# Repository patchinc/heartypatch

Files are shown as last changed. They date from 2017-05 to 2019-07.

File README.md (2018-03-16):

ProtoCentral Hearty Patch Single-lead ECG monitor
=======================================================

This repository contains the hardware, firmware and GUI software plans for the HeartyPatch single-lead ECG and R-R interval monitoring device.

## Detailed documentation is available at [heartypatch.protocentral.com](http://heartypatch.protocentral.com/)

For details and updates, check out our Hackaday Page: [https://hackaday.io/project/21046-heartypatch-a-single-lead-ecg-hr-patch-with-esp32](https://hackaday.io/project/21046-heartypatch-a-single-lead-ecg-hr-patch-with-esp32)

You can now buy HeartyPatch at https://www.crowdsupply.com/protocentral/heartypatch

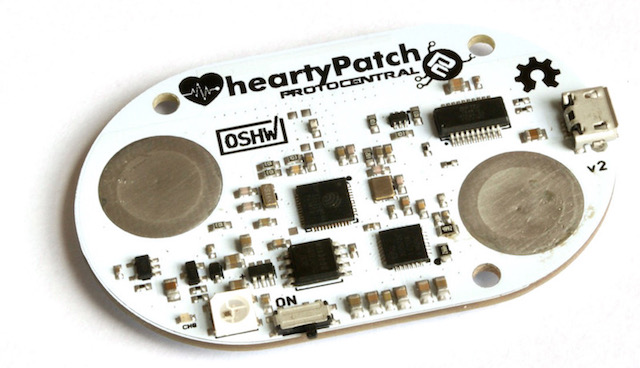
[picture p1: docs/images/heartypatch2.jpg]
HeartyPatch


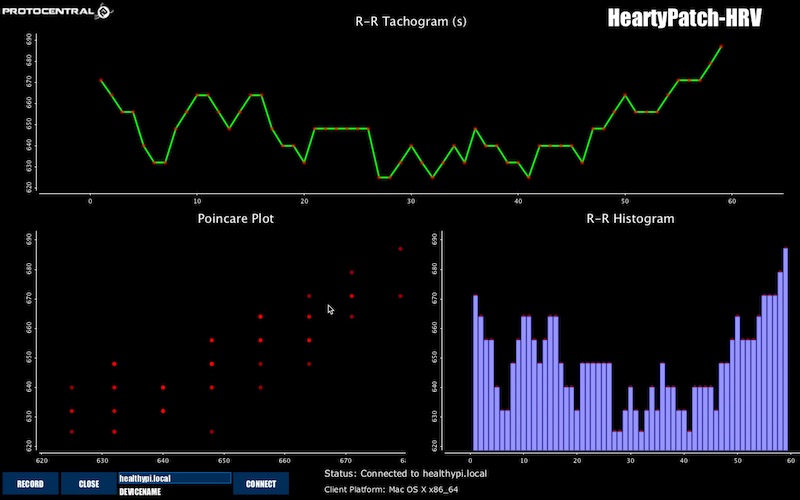
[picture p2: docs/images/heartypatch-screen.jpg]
HeartyPatch Screenshot


License Information
===================

This product is open source! Both, our hardware and software are open source and licensed under the following licenses:

Hardware
---------

**All hardware is released under [Creative Commons Share-alike 4.0 International](http://creativecommons.org/licenses/by-sa/4.0/).**


You are free to:

* Share — copy and redistribute the material in any medium or format
* Adapt — remix, transform, and build upon the material for any purpose, even commercially.
The licensor cannot revoke these freedoms as long as you follow the license terms.

Under the following terms:

* Attribution — You must give appropriate credit, provide a link to the license, and indicate if changes were made. You may do so in any reasonable manner, but not in any way that suggests the licensor endorses you or your use.
* ShareAlike — If you remix, transform, or build upon the material, you must distribute your contributions under the same license as the original.

Software
--------

**All software is released under the MIT License(http://opensource.org/licenses/MIT).**

THE SOFTWARE IS PROVIDED "AS IS", WITHOUT WARRANTY OF ANY KIND, EXPRESS OR IMPLIED, INCLUDING BUT NOT LIMITED TO THE WARRANTIES OF MERCHANTABILITY, FITNESS FOR A PARTICULAR PURPOSE AND NONINFRINGEMENT. IN NO EVENT SHALL THE AUTHORS OR COPYRIGHT HOLDERS BE LIABLE FOR ANY CLAIM, DAMAGES OR OTHER LIABILITY, WHETHER IN AN ACTION OF CONTRACT, TORT OR OTHERWISE, ARISING FROM, OUT OF OR IN CONNECTION WITH THE SOFTWARE OR THE USE OR OTHER DEALINGS IN THE SOFTWARE.

Please check [*LICENSE.md*](LICENSE.md) for detailed license descriptions.

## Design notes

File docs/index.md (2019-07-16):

---
layout: page
homepage: true
---

# Welcome to HeartyPatch
The HeartyPatch

HeartyPatch is a completely open source, single-lead, ECG-HR wearable patch with HRV (Heart Rate Variability) analysis. It is based on the popular ESP32 system-on-a-chip.

If you don't already have one, you can buy one on our [Crowd Supply](https://www.crowdsupply.com/protocentral/heartypatch) campaign page. We have started shipping them out to backers.

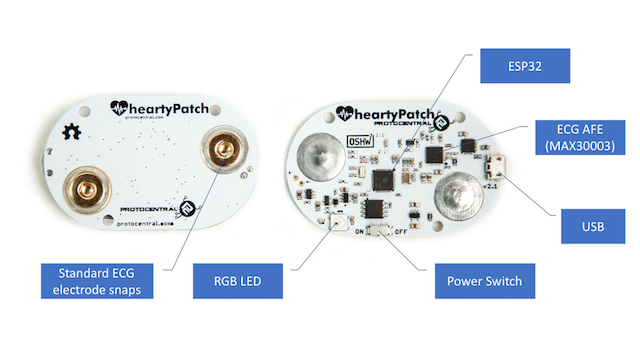
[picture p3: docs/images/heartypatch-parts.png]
HeartyPatch Parts


# Getting Started with HeartyPatch

If you just want to use the HeartyPatch with the pre-loaded firmware, it comes ready to go. You do not have to do any programming to get it working. The pre-loaded firmware send HRV values over BLE.

<iframe src="https://player.vimeo.com/video/249182147" width="640" height="360" frameborder="0" webkitallowfullscreen mozallowfullscreen allowfullscreen></iframe>

## The HeartyPatch App for Android - BETA

An android app for HeartyPatch is now available that receives and displays the real-time heart rate as well as HRV trends and variables. The app scans for any HeartyPatch devices in the vicinity and shows a list of devices accessible through Bluetooth Low Energy (BLE). Please note that you would need an Android device with BLE support to use this app.

You can download and install the app from the [Google Play Store](https://play.google.com/store/apps/details?id=com.protocentral.heartypatch) in the following link:

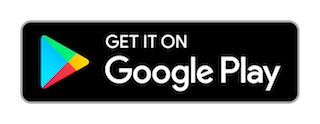
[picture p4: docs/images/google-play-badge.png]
HeartyPatch App for Android (https://play.google.com/store/apps/details?id=com.protocentral.heartypatch)


*Note: The android app for HeartyPatch is still in BETA and there might be some instability as a result.*

*Note: HeartyPatch can also be used with any Android app that supports the heart-rate profile.*

# Modes of operation

HeartyPatch at any time can work in only ONE of the following modes. Wi-Fi and BLE do not work together as of now.

## Bluetooth LE Mode
With the preloaded firmware, the HeartyPatch will do heart-rate and R-R interval measurement and send it over BLE through a standard [Heart-rate BLE service](https://www.bluetooth.com/specifications/gatt/viewer?attributeXmlFile=org.bluetooth.service.heart_rate.xml), as well as a separate custom HRV service that will provide parameters used for HRV analysis such as SD, Mean RR, PNN50 and SDNN.

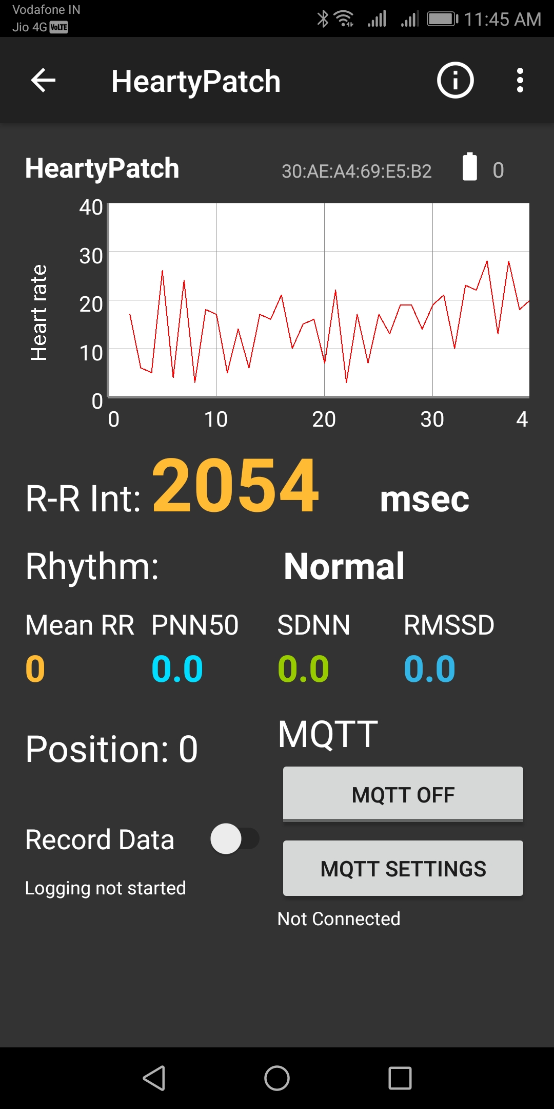
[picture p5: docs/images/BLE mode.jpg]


## Continuous ECG Streaming mode over WiFi/TCP

The HeartyPatch can also do live ECG streaming from the chest. This works similar to a heart-rate monitor. Below is a screen capture of the device working in ECG mode. The data is sent over a TCP socket over WiFi. To get the WiFi mode turned on, you will have to [flash a different firmware onto the device](#continuous-ecg-streaming-mode-over-wifitcp).

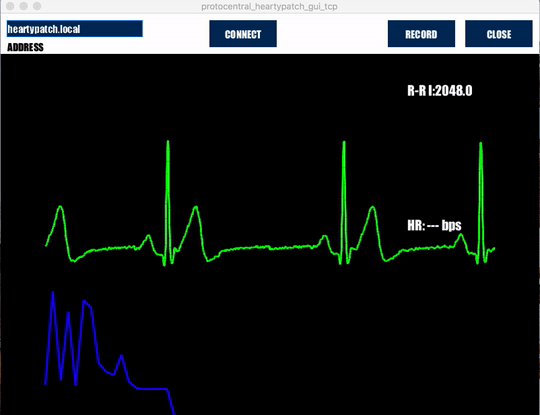
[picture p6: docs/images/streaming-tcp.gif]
HeartyPatch Streaming ECG


# Updating the firmware

It is important to always keep your firmware up-to-date for best results. We keep adding changes, bug fixes and enhancements as and when we do updates. HeartyPatch will continue to be developed and new features added.

Be on the lookout for new firmware releases on our Github releases page at https://github.com/Protocentral/protocentral_heartypatch

Download the latest binary files from the [HeartyPatch Github releases page](https://github.com/Protocentral/protocentral_heartypatch/releases/latest). Binary file names end with xx_bin.zip.

Unzip the files into a folder. Now, plug in your HeartyPatch to your computer through any USB port and follow the following procedures according to your computer's operating system.

## Updating the firmware on MacOS/linux

[esptool](https://github.com/espressif/esptool) is a Python-based utlity program to download binary files onto ESP32 chips. Please follow the following steps to install esptool.

Before starting, you will need to make sure you have Python 2/3 installed on your computer.

Open the termimal on your MacOS/Linux computer and run the command given below to download latest stable esptool.py release.
```c
pip install esptool
```
Now you should be able to run *esptool.py* from the command line. If installation fails, please refer to the [esptool page](https://github.com/espressif/esptool) for possible solutions.

Download the latest binary files from the [HeartyPatch Github releases page](https://github.com/Protocentral/protocentral_heartypatch/releases/latest). Binary file names end with xx_bin.zip.

Unzip the files into a folder.

Now, plug in your HeartyPatch to your computer through any USB port and run the following command from the same folder in which you have unzipped the files.

## Updating BLE firmware in your Heartypatch device 
* Open the unzipped Heartypatch BLE bin files path in your terminal
* Run the command given below

```c
esptool.py --port <your-port-name> write_flash --flash_mode dio --flash_freq 40m --flash_size detect 0x1000 bootloader.bin 0x10000 HeartyPatchBle.bin 0x8000 partitions_singleapp.bin
```

## Updating TCP firmware in your Heartypatch device
* Open the unzipped Heartypatch TCP bin files path in your terminal
* Run the command given below

```c
esptool.py --port <your-port-name> write_flash --flash_mode dio --flash_freq 40m --flash_size detect 0x1000 bootloader.bin 0x10000 heartypatch_tcp.bin 0x8000 partitions_singleapp.bin
```

* We have hardcoded the SSID and Password, hence you have to connect your system with the below provided ssid and password.
* Create a hotspot with ssid and password given below
* SSID - Heartypatch
* Password - 12345678
* Once firmware uploaded connect your system with the created hotspot to see TCP output in processing GUI.

Make sure to replace *<your-port-name>* with the name of the port to which your HeartyPatch. If you get a permission denied error, please run this in "sudo" mode.

If all goes well, you should see the following output on the terminal.

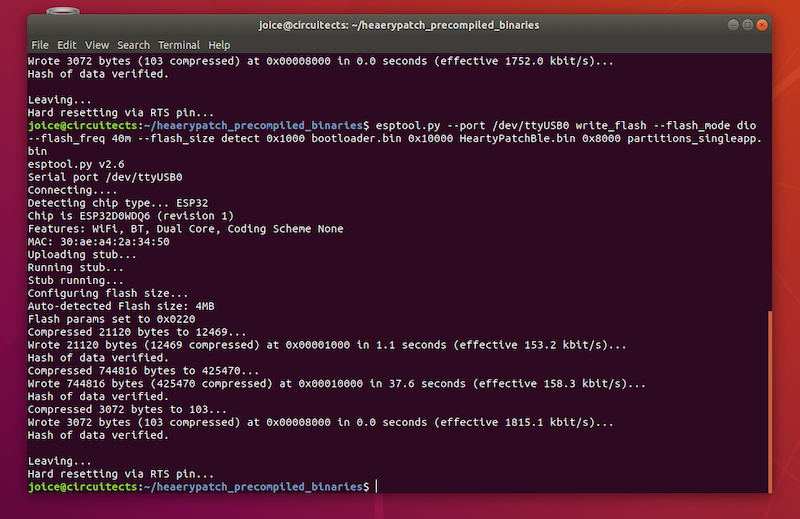
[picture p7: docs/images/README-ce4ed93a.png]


Congratulations ! You have now successfully uploaded the firmware to your HeartyPatch.

## Updating the firmware on Windows

The ESP32 Flash Download Tool is the official Espressif Download tool that runs on Windows platform. The tool can be used to modify and generate init BINs, generate consolidated BIN files or program multiple chips for production runs.

### Installing ESP32 Flash Download Tool

* Download the ESP32 tool from [Espressif's website in tools section](https://www.espressif.com/en/products/hardware/esp32/resources) as shown below

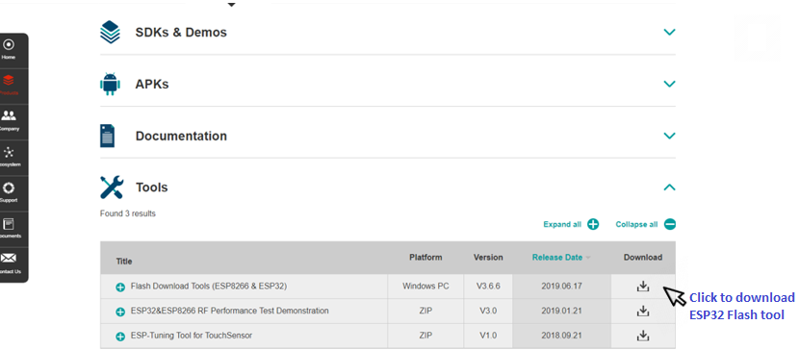
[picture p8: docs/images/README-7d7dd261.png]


* Once downloaded, open the flash_download_tools_v3.6.6.exe application from the downloaded folder as shown below

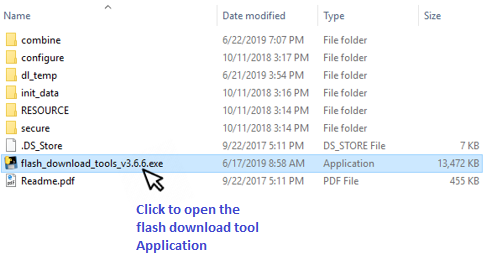
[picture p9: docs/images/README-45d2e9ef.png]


* When the program opens, select *ESP32 Download tool* from the buttons.

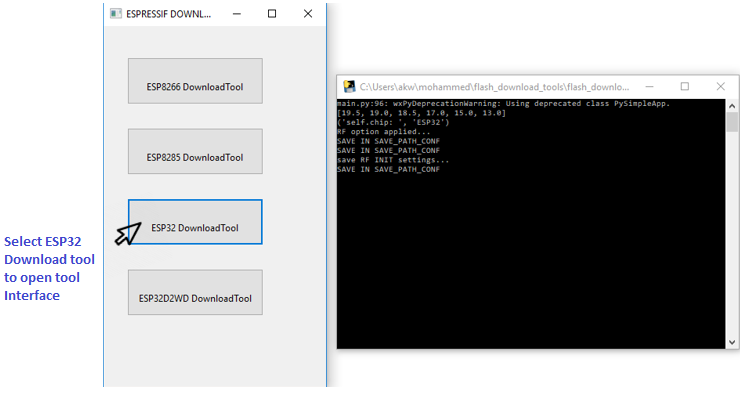
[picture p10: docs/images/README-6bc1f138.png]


* In the resulting window that opens, make sure to select the following options
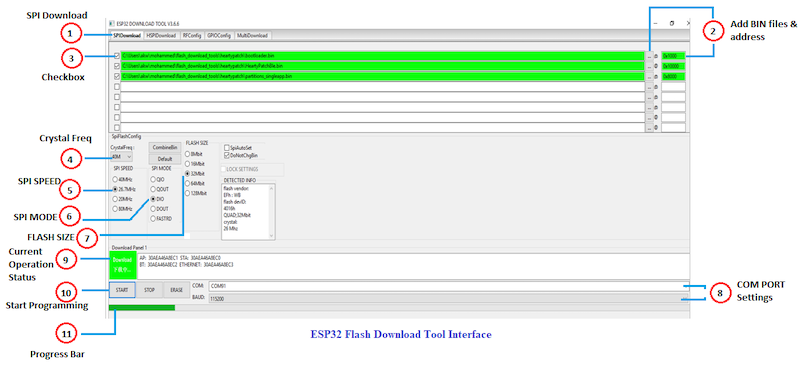
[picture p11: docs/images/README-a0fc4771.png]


1.	SPI download tab. In general, you should use SPI download mode.

2.	Add the bin files downloaded earlier to the ESP32 download tool interface one by one as listed below.

### Heartypatch BLE Command

    * bootloader.bin                   0x1000              
    * HeartyPatchBle.bin               0x10000           
    * partitions_singleapp.bin         0x8000    

### Heartypatch TCP Command

    * bootloader.bin                   0x1000              
    * heartypatch_tcp.bin              0x10000           
    * partitions_singleapp.bin         0x8000 

3.	Click on the check boxes to select the bin files.
4.	Crystal Frequency for heartypatch should be set as 40M.
5.	SPI Flash speed for heartypatch should be set as 26.7MHz.
6.	SPI Mode for heartypatch should be set as DIO mode.
7.	Flash memory size for heartypatch should be set as 32Mbit.
8.	Select the port number of your heartypatch device and set baud rate to 115200.
9.	Current status: Tells about the current operation status. Whether the download tool is idle or running, etc.
10. Click Start button to start programming.
11.	Progress bar indicates firmware uploads program. Once bin files is uploaded the indication status displays finish.
12.	Program displays PHY MAC IDs for Wi-Fi, BLE, ethernet, etc.

Congratulations ! You have now successfully uploaded the firmware to your HeartyPatch.

# Compiling your own firmware (advanced, optional)

The firmware for the HeartyPatch's on-board Espressif ESP32 chip uses the [esp-idf framework](https://github.com/espressif/esp-idf)
 for development. You will need to install and configure the following components to setup a development environment:

* **The Xtensa ESP32 toolchain**
  Please make sure to download the toolchain from the [Espressif Setup Guide for v2.1](http://esp-idf.readthedocs.io/en/v2.1/get-started/index.html#standard-setup-of-toolchain)

  This version of the esp-idf compiles well only with the toolchain version 1.22.0-61-gab8375a-5.2.0.

* **The v2.1 release of esp-idf**
  *The current version of the HeartyPatch code compiles well and performs well only with v2.1 of the ESP-IDF and version 1.22.0-61-gab8375a-5.2.0 of the Xtensa toolchain.*

  [Download the ESP-IDF version 2.1 here](https://github.com/espressif/esp-idf/releases/download/v2.1/esp-idf-v2.1.zip)

  Setup guides for these components are available on the [ESP-IDF documentation site](https://esp-idf.readthedocs.io/en/v2.1/get-started/index.html).

* Clone our [Github repository](https://github.com/Protocentral/protocentral_heartypatch) of code for the ESP32:

  `git clone https://github.com/Protocentral/protocentral_heartypatch.git`

  [or download a zip file of the latest master branch](https://github.com/Protocentral/protocentral_heartypatch/archive/master.zip).

* Download this zip file, rename it to whatever you want to. Change to this directory and then start building.

`Please make sure that correct version of all of the above tools are installed before proceeding.`

The folder "heartypatch-ble" in the "Firmware" contains the code for the preloaded firmware on the HeartyPatch, which calculates R-R interval, heart rate and time domain parameters for HRV analysis and sends them through BLE.

Now that you have the code and ready to build, you will need to configure the build options for heartypatch through menuconfig utility:

* Open the terminal and navigate to the folder which contains the heartypatch code 	
* Start the project configuration utility **menuconfig**     		
  `make menuconfig`

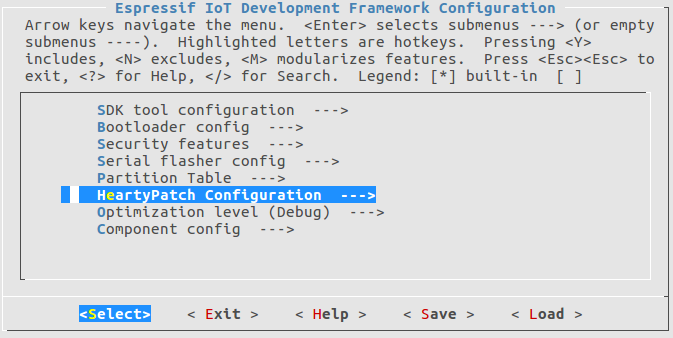
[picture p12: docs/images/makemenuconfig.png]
menuconfig
  

* Configure your serial port under *Serial flasher config -> Default serial port*

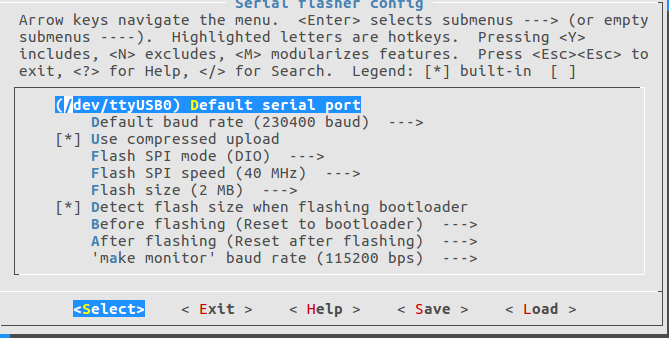
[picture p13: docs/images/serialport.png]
port
  

* Use the *Heartypatch configuration* to enable BLE mode

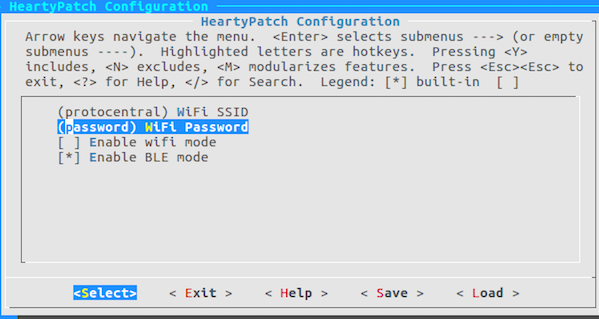
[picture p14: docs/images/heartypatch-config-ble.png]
heartypatch-config
  

BLE mode at this time does not support ECG stream since the MAX30003 sensor is configured for R-R detection only. By enabling the wifi, you may get hr and rr values through TCP in the Heartypatch GUI. For ECG stream you may use the heartypatch-stream-tcp code [protocentral-heartypatch/firmware/heatypatch-stream-tcp]

* Navigate to component config -> esp32-specific ->main XTAL frequency and select 26 Mhz as the board crystal

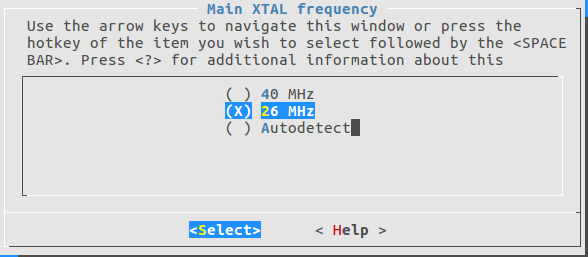
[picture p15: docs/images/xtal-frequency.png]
Setting crystal freqency
  

* Save the configuration by selecting `<save>` and close menuconfig

* Run the makefile (assuming previous steps are done correctly):

  `make` or `make -j5`

* To flash the firmware on to the board, just use:

  `make flash`

  If the flashing is successful, you should see something similar to the below screen:

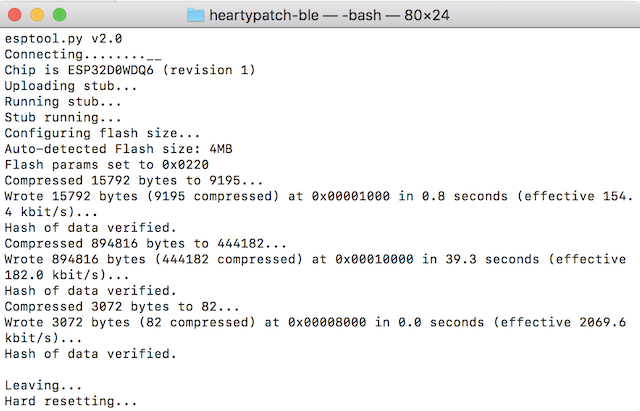
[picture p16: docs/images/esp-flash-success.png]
ESP Success
  

# Continuous ECG mode

The folder `heartypatch-stream-tcp` contains the code for streaming ECG.

Before flashing this code, enable wifi, TCP and mdns through `makemenuconfig` similar to the process described in the previous section.

* Start makemenuconfig and navigate to *Heartypatch configuration*, set your wifi ssid and password, enable mdns and TCP:
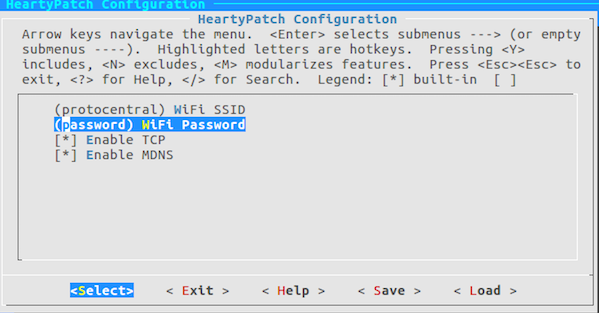
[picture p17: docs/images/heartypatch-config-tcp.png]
Heartypatch config
  

* Configure the serial port under Serial flasher config -> Default serial port
* Navigate to *Component config -> esp32-specific ->main XTAL frequency* and select 26 MHz as the board crystal

Run the makefile (assuming previous steps are done correctly):

`make` or `make -j5`

To flash the firmware on to the board, just use:

`make flash`

If the flashing is successful, you should see something similar to the below screen:

ESP Success

You can open the IDF monitor to see the debug messages by using the command:

`make monitor`

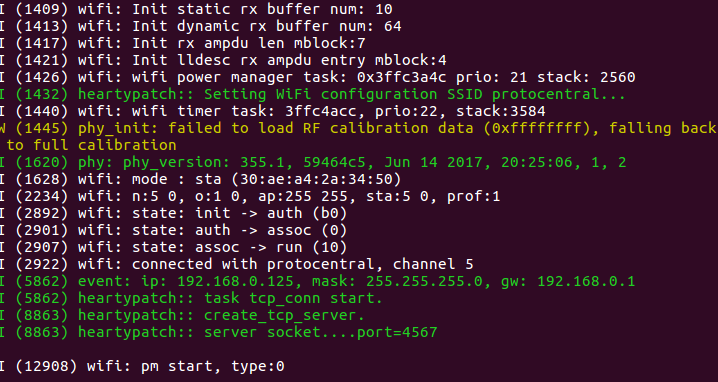
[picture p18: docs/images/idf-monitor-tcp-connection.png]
idf-monitor


Once the heartypatch is connected with the wifi, open the gui from the project folder and you should be able see the ECG stream.  

More information about this process and the ESP32 framework is available in the [ESP32 Get Started Guide](http://esp-idf.readthedocs.io/en/latest/get-started/).

# The TCP Client GUI

The HeartyPatch is now configured as a TCP sever ready for connection from a TCP client. The HeartyPatch sends data out in the following packet format.

| Offset| Byte Value  | Description|
------  | ----------- | -----------
| 0     | 0x0A | Start of frame
| 1     | 0xFA | Start of frame
| 2     | Payload Size LSB |
| 3     | Payload Size MSB |
| 4     | Protocol version | (currently 0x03)
|5-8    | Packet sequence | incremental number
|9-16   | Timestamp | From ESP32 gettimeofday()
|17-20  | R-R Interval |
|18-... | ECG Data samples | Currently 8 samples / packet|
|...    | 0x0B | End of Frame|

You can download the ProtoCentral TCP client GUI for your platform from the following link.

[Download TCP Client GUI](https://github.com/Protocentral/protocentral_heartypatch/releases/latest)

After you unzip and run the executable program on your computer, choose the default address (heartypatch.local) and click connect. You should see a screen like this:

HeartyPatch Streaming ECG

# Frequently Asked Questions

* **Why is the heart-rate not stable? There's always variation.**

  Do not worry, that's what is [Heart-rate variability](https://en.wikipedia.org/wiki/Heart_rate_variability) and HeartyPatch displays real-time beat-to-beat heart rate. Heart-rate is supposed to vary from beat-to-beat.

* **How do I get the full ECG signal from the device?**

  Please read our [Guide to program the device the TCP Streaming mode](#continuous-ecg-mode)

* **I have problems getting the code to compile. What do I do?**

  Most of the problems in compilation arise from having the wrong versions of the ESP-IDF. Please make sure the versions of the esp-idf as well as the Xtensa toochain match the ones given in out [Guide to firmware upgrades](#updating-the-firmware)

* **Help, there is not LED flashing on the device.**

  By default, the LED would not flash. This is done to conserve battery power. This can be enabled in the software though.

* **Why is the ECG  signal too noisy?**

  Noise is very common in ECG systems and they usually use filters to take them out. The HeartyPatch already has hardware as well as software filters to remove noise. However, there are still some conditions which can cause the signal to be noisy:

    * Contact is key. Make sure that the electrode pad is fully flat on the body and it is positioned properly.
    * Make sure that the position of the HeartyPatch is correct (refer to the video). Other positions may not provide a strong signal
    * Do not use the HeartyPatch on the body while it is connected to the USB cable. Always remove the cable before wearing the HeartyPatch.
    * A common source of noise is dry skin. Dry skin does not give good electrical conductivity.
    * Do not re-use ECG electrodes. The quality of contact would reduce with each use.

*We will continue to add to this list based on user input, so please check this list if something goes wrong.*

# License Information

This product is open source! Both, our hardware and software are open source and licensed under the following licenses:

## Hardware

All hardware is released under [Creative Commons Share-alike 4.0 International](http://creativecommons.org/licenses/by-sa/4.0/).



## Software

All software is released under the MIT License(http://opensource.org/licenses/MIT).

Please check [*LICENSE.md*](LICENSE.md) for detailed license descriptions.

THE SOFTWARE IS PROVIDED "AS IS", WITHOUT WARRANTY OF ANY KIND, EXPRESS OR IMPLIED, INCLUDING BUT NOT LIMITED TO THE WARRANTIES OF MERCHANTABILITY, FITNESS FOR A PARTICULAR PURPOSE AND NON-INFRINGEMENT. IN NO EVENT SHALL THE AUTHORS OR COPYRIGHT HOLDERS BE LIABLE FOR ANY CLAIM, DAMAGES OR OTHER LIABILITY, WHETHER IN AN ACTION OF CONTRACT, TORT OR OTHERWISE, ARISING FROM, OUT OF OR IN CONNECTION WITH THE SOFTWARE OR THE USE OR OTHER DEALINGS IN THE SOFTWARE.

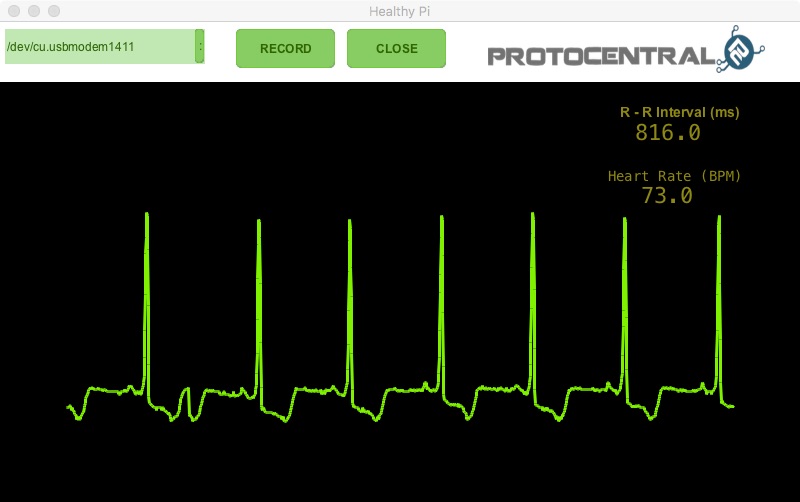
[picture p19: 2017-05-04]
docs/images/max30003_gui_screenshot.jpg

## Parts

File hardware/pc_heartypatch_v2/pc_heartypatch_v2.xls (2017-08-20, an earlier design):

pc_heartypatfch
Qty | Value | Parts | Package
4 | 0.1uF | C20, C36, C37, C41 | 603
4 | 0.1uF | C12, C18,C32, C39 | C0402
1 | 1.0uF | C40 | 603
3 | 1.0uF | C11, C15, C16 | 805
1 | 1.0uF | C19 | C0402
1 | 1000pF | C3 | C0402
1 | 100pF | C35 | 603
1 | 10nF | C31 | 603
2 | 10pF | C27, C28 | 603
2 | 10pF | C9, C10 | C0402
1 | 10uF | C14,C38 | C0603
4 | 10uF | C4, C6, C7, C17 | C0805
2 | 15pF | C42, C43 | 603
1 | 1nF | C2 | C0603
1 | 1uF | C5 | C0402
1 | 1uF | C1 | C0603
2 | 1uF | C8, C13 | C0805
1 | 2.4pF | C33 | 603
1 | 270pF | C30 | 603
1 | 3.0nF | C44 | 603
2 | 4.7u | C21, C22 | C0805
1 | 10K | R20 | R0402
5 | 10k | R1, R2, R3, R21, R29, R30,R33 | 603
1 | 20k | R22 | 603
2 | 1K | R12, R13 | R0402
1 | 1k | R19 | R0402
2 | 49.9K | R4, R5 | 805
1 | 5.6pF | C34 | 603
1 | 330R | R18 | R0402
2 | 27R | R9, R10 | R0402
1 | AP7312 | U$3 | SOT26
1 | BAT20J | D3 | SOD-323
1 | ESP3212 | U10 | QFN48-0.4MM
1 | FTS31XS-U | U4 | SSOP20_L
1 | MAX30003CTI+ | U$1 | QFN-28
1 | MBT3904DW1T1 | Q5 | SC70-6
1 | MCP73831 | U5 | SOT23-5
1 | MICRO-B | JP7 | MICRO-B
1 | PCM12SMTR | S1 | SWITCH-SPST-SMD-A
1 | RED | CHG1 | CHIPLED_0603
1 | W25Q32FVSS | U6 | SOIC-8
1 | WS2812B5050 | LED1 | WS2812B
1 | 2.5A/30V | Q3 | SOT23-3
1 | 2.7nH | L3 | 603
1 | 32.768kHz | Y3 | CRYSTAL-SMD-3.2X1.5MM

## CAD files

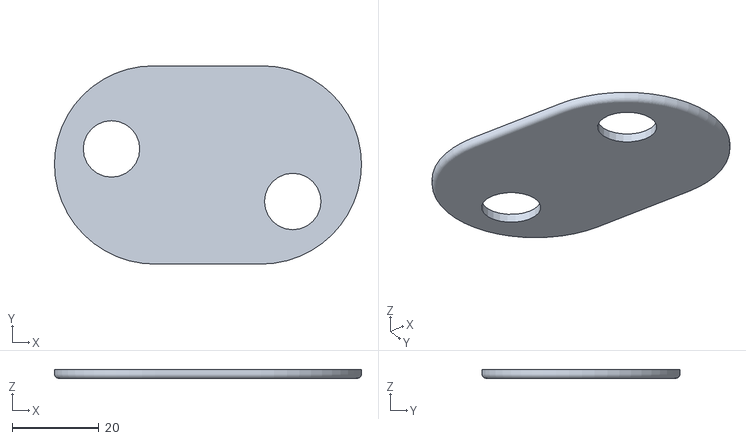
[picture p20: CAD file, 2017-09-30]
hardware/enclosure/heartypatch_case_v2.1/HeartyPatch_ case_v2.1_bottom.stl
70.6 x 45.6 x 2.00

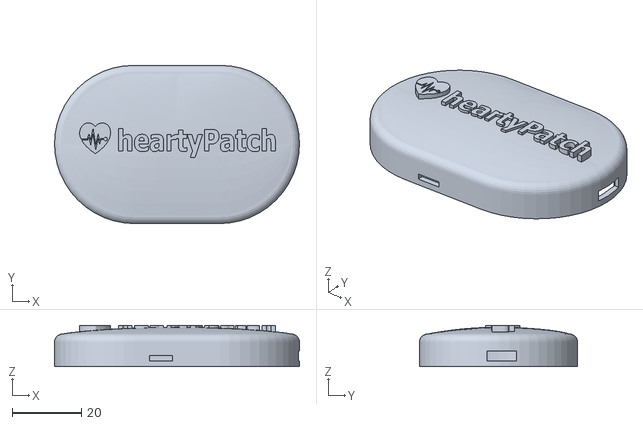
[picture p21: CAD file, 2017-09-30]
hardware/enclosure/heartypatch_case_v2.1/HeartyPatch_ case_v2.1_top.stl
70.6 x 45.6 x 11.9

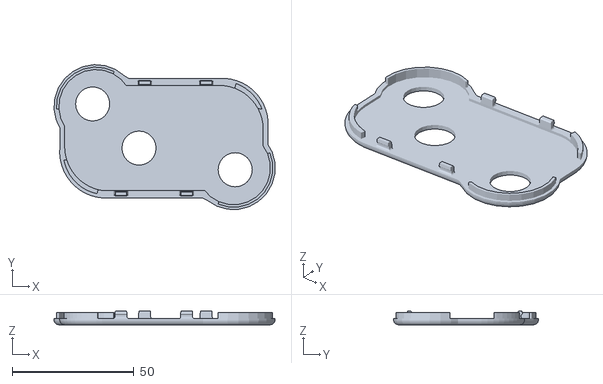
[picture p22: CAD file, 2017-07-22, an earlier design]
hardware/enclosure/heartypatch_case_v1/PCB Bottom Cover with hooks - ShWallHt.stl
90.7 x 59.4 x 5.61

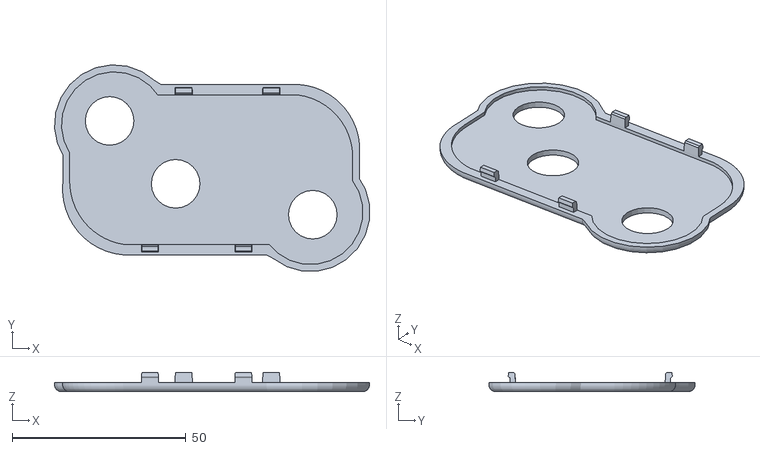
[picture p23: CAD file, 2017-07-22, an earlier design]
hardware/enclosure/heartypatch_case_v1/PCB Bottom Cover with hooks.stl
90.7 x 59.4 x 5.61

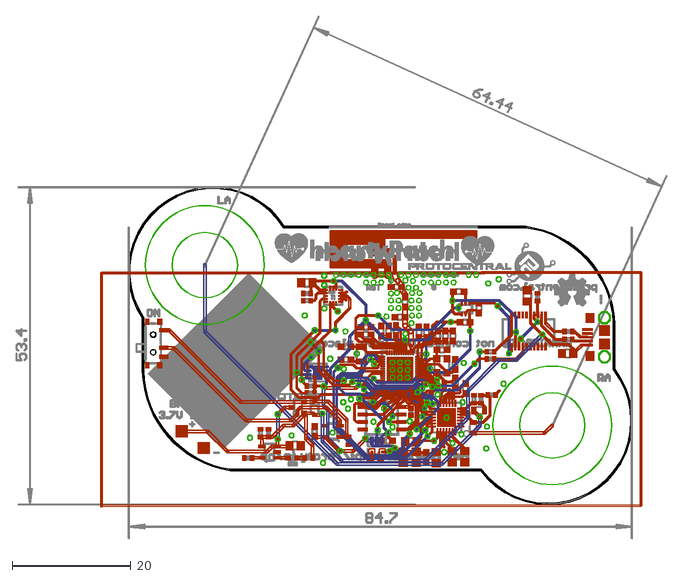
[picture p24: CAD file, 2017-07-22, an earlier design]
hardware/enclosure/heartypatch_case_v1/pc_heartypatch.dxf
109.6 x 87.9

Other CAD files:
hardware/enclosure/heartypatch_case_v1/PCB Bottom Cover with hooks - ShWallHt (1).stl
hardware/enclosure/heartypatch_case_v1/heartyPatch top.skp

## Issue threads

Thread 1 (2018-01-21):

Heart rate returned seems unstable.

ozarchie, 2018-01-21:
I received a HP V2.3 and connected it as per the online video.
I installed the APK on a Nexus7, but the HR value was variable, so I decided to update the firmware.
I installed ESP, and the GITHUB firmware code.
I installed Eclipse as per ESP instructions and compiled and flashed the GITHUB version.
All proceeded correctly,  compiled without errors and flashed without errors.

```
Target 'component-xtensa-debug-module-build' responsible for '/Users/John/esp/heartypatch-ble/build/xtensa-debug-module/libxtensa-debug-module.a'
Flashing binaries to serial port /dev/cu.usbserial-DN02SY6M (app at offset 0x10000)...
python /Users/John/esp/esp-idf/components/esptool_py/esptool/esptool.py --chip esp32 --port "/dev/cu.usbserial-DN02SY6M" --baud 115200 --before "default_reset" --after "hard_reset" write_flash -z --flash_mode "dio" --flash_freq "40m" --flash_size detect 0x1000 /Users/John/esp/heartypatch-ble/build/bootloader/bootloader.bin 0x10000 /Users/John/esp/heartypatch-ble/build/gatt_server_demos.bin 0x8000 /Users/John/esp/heartypatch-ble/build/partitions_singleapp.bin
esptool.py v2.1
Connecting....
Chip is ESP32D0WDQ6 (revision 1)
Uploading stub...
Running stub...
Stub running...
Configuring flash size...
Auto-detected Flash size: 4MB
Flash params set to 0x0220
Compressed 19376 bytes to 11439...

Writing at 0x00001000... (100 %)
Wrote 19376 bytes (11439 compressed) at 0x00001000 in 1.0 seconds (effective 151.4 kbit/s)...
Hash of data verified.
Compressed 730160 bytes to 391849...

Writing at 0x00010000... (4 %)
Writing at 0x00014000... (8 %)
Writing at 0x00018000... (12 %)
Writing at 0x0001c000... (16 %)
Writing at 0x00020000... (20 %)
Writing at 0x00024000... (25 %)
Writing at 0x00028000... (29 %)
Writing at 0x0002c000... (33 %)
Writing at 0x00030000... (37 %)
Writing at 0x00034000... (41 %)
Writing at 0x00038000... (45 %)
Writing at 0x0003c000... (50 %)
Writing at 0x00040000... (54 %)
Writing at 0x00044000... (58 %)
Writing at 0x00048000... (62 %)
Writing at 0x0004c000... (66 %)
Writing at 0x00050000... (70 %)
Writing at 0x00054000... (75 %)
Writing at 0x00058000... (79 %)
Writing at 0x0005c000... (83 %)
Writing at 0x00060000... (87 %)
Writing at 0x00064000... (91 %)
Writing at 0x00068000... (95 %)
Writing at 0x0006c000... (100 %)
Wrote 730160 bytes (391849 compressed) at 0x00010000 in 34.9 seconds (effective 167.4 kbit/s)...
Hash of data verified.
Compressed 3072 bytes to 82...
Writing at 0x00008000... (100 %)
Wrote 3072 bytes (82 compressed) at 0x00008000 in 0.0 seconds (effective 1017.9 kbit/s)...
Hash of data verified.
Leaving...
Hard resetting...
19:43:48 Build Finished (took 44s.339ms)

```
Below is the output of the device connected via USB to the Eclipse monitor.
Either I should be buying a coffin, or something is wrong :)

```
Connected to /dev/cu.usbserial-DN02SY6M at 115200
�ets Jun  8 2016 00:22:57

rst:0x1 (POWERON_RESET),boot:0x13 (SPI_FAST_FLASH_BOOT)
configsip: 0, SPIWP:0xee
clk_drv:0x00,q_drv:0x00,d_drv:0x00,cs0_drv:0x00,hd_drv:0x00,wp_drv:0x00
mode:DIO, clock div:2
load:0x3fff0018,len:4
load:0x3fff001c,len:5544
load:0x40078000,len:0
ho 12 tail 0 room 4
load:0x40078000,len:13724
entry 0x40078fb4
 [0;32mI (30) boot: ESP-IDF v3.1-dev-133-g7d0d2854 2nd stage bootloader [0m
 [0;32mI (30) boot: compile time 19:36:35 [0m
 [0;32mI (39) boot: Enabling RNG early entropy source... [0m
 [0;32mI (39) boot: SPI Speed      : 40MHz [0m
 [0;32mI (39) boot: SPI Mode       : DIO [0m
 [0;32mI (43) boot: SPI Flash Size : 4MB [0m
 [0;32mI (47) boot: Partition Table: [0m
 [0;32mI (51) boot: ## Label            Usage          Type ST Offset   Length [0m
 [0;32mI (58) boot:  0 nvs              WiFi data        01 02 00009000 00006000 [0m
 [0;32mI (66) boot:  1 phy_init         RF data          01 01 0000f000 00001000 [0m
 [0;32mI (73) boot:  2 factory          factory app      00 00 00010000 00100000 [0m
 [0;32mI (81) boot: End of partition table [0m
 [0;32mI (85) esp_image: segment 0: paddr=0x00010020 vaddr=0x3f400020 size=0x2f48c (193676) map [0m
 [0;32mI (161) esp_image: segment 1: paddr=0x0003f4b4 vaddr=0x3ffc0000 size=0x00b5c (  2908) load [0m
 [0;32mI (163) esp_image: segment 2: paddr=0x00040018 vaddr=0x400d0018 size=0x6ccf8 (445688) map [0m
 [0;32mI (322) esp_image: segment 3: paddr=0x000acd18 vaddr=0x3ffc0b5c size=0x02054 (  8276) load [0m
 [0;32mI (326) esp_image: segment 4: paddr=0x000aed74 vaddr=0x40080000 size=0x00400 (  1024) load [0m
 [0;32mI (330) esp_image: segment 5: paddr=0x000af17c vaddr=0x40080400 size=0x1327c ( 78460) load [0m
 [0;32mI (370) esp_image: segment 6: paddr=0x000c2400 vaddr=0x400c0000 size=0x00000 (     0) load [0m
 [0;32mI (382) boot: Loaded app from partition at offset 0x10000 [0m
 [0;32mI (382) boot: Disabling RNG early entropy source... [0m
 [0;32mI (382) cpu_start: Pro cpu up. [0m
 [0;32mI (386) cpu_start: Starting app cpu, entry point is 0x40080f60 [0m
 [0;32mI (0) cpu_start: App cpu up. [0m
 [0;32mI (397) heap_init: Initializing. RAM available for dynamic allocation: [0m
 [0;32mI (403) heap_init: At 3FFAFF10 len 000000F0 (0 KiB): DRAM [0m
 [0;32mI (409) heap_init: At 3FFCAD98 len 00015268 (84 KiB): DRAM [0m
 [0;32mI (415) heap_init: At 3FFE0440 len 00003BC0 (14 KiB): D/IRAM [0m
 [0;32mI (422) heap_init: At 3FFE4350 len 0001BCB0 (111 KiB): D/IRAM [0m
 [0;32mI (428) heap_init: At 4009367C len 0000C984 (50 KiB): IRAM [0m
 [0;32mI (434) cpu_start: Pro cpu start user code [0m
 [0;32mI (5) cpu_start: Starting scheduler on PRO CPU. [0m
 [0;32mI (0) cpu_start: Starting scheduler on APP CPU. [0m
 [0;32mI (2046) gpio: GPIO[27]| InputEn: 1| OutputEn: 0| OpenDrain: 0| Pullup: 0| Pulldown: 1| Intr:1  [0m
 [0;32mI (4046) system_api: Base MAC address is not set, read default base MAC address from BLK0 of EFUSE [0m
 [0;32mI (4226) phy: phy_version: 366.0, ba9923d, Oct 31 2017, 18:06:17, 1, 0 [0m
 [0;32mI (4256) HeartyPatch: REGISTER_APP_EVT, status 0, app_id 0
 [0m
 [0;32mI (4256) HeartyPatch: CREATE_SERVICE_EVT, status 0,  service_handle 40
 [0m
 [0;32mI (4266) HeartyPatch: CREATE_SERVICE_EVT, status 0,  service_handle 44
 [0m
 [0;32mI (4266) HeartyPatch: REGISTER_APP_EVT, status 0, app_id 2
 [0m
 [0;32mI (4276) HeartyPatch: CREATE_SERVICE_EVT, status 0,  service_handle 48
 [0m
 [0;32mI (5026) HeartyPatch: GATT_READ_EVT, conn_id 0, trans_id 4, handle 42
 [0m
 [0;32mI (5126) HeartyPatch: GATT_WRITE_EVT, conn_id 0, trans_id 5, handle 43
 [0m
 [0;32mI (5126) HeartyPatch: GATT_WRITE_EVT, value len 2, value 00000001
 [0m
 [0;32mI (5216) HeartyPatch: GATT_READ_EVT, conn_id 0, trans_id 6, handle 43
 [0m
 [0;32mI (5416) HeartyPatch: GATT_WRITE_EVT, conn_id 0, trans_id 8, handle 47
 [0m
 [0;32mI (5416) HeartyPatch: GATT_WRITE_EVT, value len 2, value 00000001
 [0m
 [0;32mI (5706) HeartyPatch: GATT_WRITE_EVT, conn_id 0, trans_id 11, handle 51
 [0m
 [0;32mI (5706) HeartyPatch: GATT_WRITE_EVT, value len 2, value 00000001
 [0m
hr 3
hr 36
hr 31
hr 31
hr 58
hr 32
hr 61
hr 66
hr 62
hr 60
hr 65
hr 39
hr 67
hr 67
hr 66
hr 61
hr 66
hr 61
hr 60
hr 62
hr 65
hr 62
hr 62
hr 64
hr 64
hr 61
hr 64
hr 66
hr 63
hr 38
hr 70
hr 71
hr 132
hr 55
hr 33
hr 66
hr 61
hr 32
hr 60
hr 60
hr 66
hr 66
hr 61
hr 61
hr 65
hr 132
hr 53
hr 65
hr 66
hr 66
hr 62
hr 139
hr 54
hr 65
hr 65
hr 67
hr 65
hr 65
hr 66
hr 67
hr 125
hr 53
hr 68
hr 69
hr 130
hr 54
hr 69
hr 69
hr 38
hr 67
hr 66
hr 63
hr 64
hr 130
hr 54
hr 63
hr 66
hr 65
hr 64
hr 67
hr 62
hr 38
hr 66
hr 65
hr 63
hr 66
hr 137
hr 53
hr 65
hr 66
hr 67
hr 65
hr 56
hr 112
hr 80
hr 18
hr 120
hr 90
hr 7
hr 65
hr 75
hr 62
hr 87
hr 94
hr 83
hr 92
hr 42
hr 66
hr 44
hr 92
hr 60
hr 13
hr 45
hr 56
hr 96
hr 96
hr 60
hr 97
hr 16
hr 44
hr 96
hr 105
hr 71
hr 120
hr 42
hr 40
hr 89
hr 87
hr 73
hr 69
hr 61
hr 76
hr 89
hr 10
hr 65
hr 66
hr 65
hr 65
hr 67
hr 16
hr 68
hr 70
hr 92
hr 77
hr 73
hr 96
hr 45
hr 29
hr 109
hr 97
hr 60
hr 23
hr 97
hr 36
hr 82
hr 43
hr 97
hr 130
hr 114
hr 153
hr 166
hr 163
hr 103
hr 144
hr 147
hr 232
hr 85
hr 121
hr 38
hr 61
hr 147
hr 106
hr 232
hr 89
hr 38
hr 202
hr 192
hr 202
hr 80
hr 102
hr 102
hr 96
hr 134
hr 66
hr 23
hr 97
hr 156
hr 207
hr 120
hr 182
hr 225
hr 99
hr 225
hr 78
hr 24
hr 142
hr 139
hr 44
hr 84
hr 153
hr 61
hr 61
hr 163
hr 93
hr 225
hr 109
hr 225
hr 31
hr 97
hr 213
hr 24
hr 132
hr 62
hr 114
hr 105
hr 56
hr 65
hr 70
hr 76
hr 27
hr 123
hr 163
hr 41
hr 65
hr 116
hr 98
hr 13
hr 69
hr 72
hr 85
hr 74
hr 23
hr 57
hr 60
hr 77
hr 123
hr 118
hr 125
hr 58
hr 81
hr 116
hr 120
hr 43
hr 13
hr 35
hr 63
hr 102
hr 105
hr 69
hr 105
hr 101
hr 150
hr 57
hr 91
hr 71
hr 51
hr 97
hr 125
hr 66
```
hr 97
hr 139
hr 137
hr 120
hr 130
hr 51
hr 66
hr 219
hr 134
hr 132
hr 137
hr 59
hr 61
hr 232
hr 225
hr 142
hr 232
hr 53
hr 128
hr 174
hr 84
hr 46
hr 11

protocentralashwin, 2018-01-21:
Thank you buying HeartyPatch !

What you're seeing is absolutely correct. The entire purpose of HeartyPatch is to study heart-rate variability. Heart-rate is supposed to change beat-to-beat. Conventional heart-rate monitors only show the average value of the heart rate. Please refer to our earlier post on Crowd Supply about HRV:

https://www.crowdsupply.com/protocentral/heartypatch/updates/heart-rate-vs-heart-rate-variability-hrv

Something is not right only if the heart-rate is very stable!

ozarchie, 2018-01-21:
So I need another device running some other program to make this useful?

protocentralashwin, 2018-01-21:
The whole idea of making HeartyPatch is for studying HRV. However, if you need only average heart-rate, you can average the values over a period of time (usually 1 minute), which is what a conventional heart-rate device does. What is your application? Accordingly you can do the averaging in the software.

ozarchie, 2018-01-21:
OK, thanks.

protocentralashwin, 2018-01-21:
We will add an average function to the app soon. Thanks for letting us know.

ozarchie, 2018-01-21:
I really don't understand or believe  a variation from 27 to 350, but I am
not a health professional.

On 22 Jan. 2018 12:06 am, "Ashwin K Whitchurch" <notifications@github.com>
wrote:

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

protocentralashwin, 2018-01-21:
That is not right of course. It is an artifact, caused by motion of the electrodes or something. We are working on algorithms to remove those artifacts and outliers.

Closed 2018-01-21.

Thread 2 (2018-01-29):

FW Upgrade issue

yursel, 2018-01-29:
I have tried to upgrade the firmware but no success.
Let me tell U the experience:

Linux machine, Ubuntu 16.04

-	xtensa-esp32-elf: I have tried both to build it (successfully) and downloading the pre-built version

-	esp-idf:  here is where the problem probably is.
On your instructions, you mention ( https://github.com/Protocentral/protocentral_heartypatch/blob/master/docs/firmware-upgrades.md ) to use “The v2.1 release of esp-idf”

If I use the checkout of v2.1, I get “make errors” in the app

If I use the checkout of V3.0-rc1, I can build, but I get an error while flashing.
I tried this use because in the dump of the device I see this is the version inside. Please give a look at the screenshot below.

If I use the checkout of V3.0 make app works, but it fails the bootloader make.

Basically, I have not been able to find a working configuration, nor to flash any firmware.

-------- ANSWER from Ashwin (very nice guy!)

I think the problem is with the toolchain. Espressif is not very clear about this. The latest version of the toolchain doesn't work well.

Can you please try out with the toolchain in the following link and let me know?

http://esp-idf.readthedocs.io/en/v2.1/get-started/linux-setup.html

The problem is that v2.1 seems to work only with this toolchain and the v3.0rc1 works with a specific version of the toolchain (not 0.80).

-------- Update on my side

Proposed solution is working, I am able to compile.

Closed 2018-01-29.

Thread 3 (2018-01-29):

Serial port not working in VMware - Solved

yursel, 2018-01-29:
I was trying to use my VM under VMware, by attaching the USB-Serial device to the serial machine.

I was able to read the RX and TX data (like when devices boots up), but not able to enter programming.

I solved the issue by creating a new "Serial port" in the "Virtual Machine Settings".
It works properly, using the standard interrupt mode (not enabling the I/O polling mode).

Hope it can help!

Y

Closed 2018-01-29.

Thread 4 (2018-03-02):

setting it up in ubuntu

sanster9292, 2018-03-02:
Hey guys,
Sorry to put it here, but i just got my heartypatch and I was wondering how i would set it up for use to play around with. I am trying to use the data for some R-R interval realted project I am working on. I was trying to find the link to download the GUI software but I couldn't find any links or tutorials for that.
Any help would be greatly appreciated

joicetm, 2019-02-27:
Hi,

I am closing this issue as it was addressed through mail, you can reopen or create new issue in case of any query

You can check our documentation site for [getting started](http://heartypatch.protocentral.com/)

To record the data you may use the log button in the heartypacth application. which will save the data to a .csv file in downloads section.

[android app](https://play.google.com/store/apps/details?id=com.protocentral.heartypatch&hl=en)

You can also use HeartyPatch GUI to recoed the data while in [TCP mode])https://github.com/Protocentral/protocentral_heartypatch/releases/tag/v1.0)

Closed 2019-02-27.

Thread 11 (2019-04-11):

[FR] Support DIY with ESP32-Dev and AD8232

aenertia, 2019-04-11:
Hi there ; I would like to use Heartypatch code base for my DIY'd ecg running on a clone esp32-dev board and ad8232.

The main challenges are some of the hardcoded assummptions about the max3000 adc chip. It would be great to refactor things a little so that any adc could be dropped in as a pin def/header def and reuse everything else.

aenertia, 2019-04-12:
the AD8232 just returns a reading over Analog ; ideally I just want a data structure where this reading can be returned into and then the rest of the code can remain the same; after undefining the max/spi stuff.

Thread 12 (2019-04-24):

Bluetooth isn´t working - Enable Controller failed

chbardel, 2019-04-24:
I get the following debug messages through serial monitor:
`I (2092) gpio: GPIO[27]| InputEn: 1| OutputEn: 0| OpenDrain: 0| Pullup: 0| Pulldown: 1| Intr:1`
`I (4092) BTDM_INIT: BT controller compile version [484c057]`
`I (4092) system_api: Base MAC address is not set, read default base MAC address from BLK0 of EFUSE`
`E (4092) HeartyPatch: heartypatch_ble_Init enable controller failed`

I wasn´t able to find it via bluetooth on my S9+ with the heartypatch, EliteHRV and various scanner apps. So i decided to reflash the newest firmware. But still I get the above mentioned error messages. Please help!

shashi100, 2019-08-21:
Where you able to resolve this issue? I have the same problem.

chbardel, 2019-08-26:
Na sadly not. Currently it remains useless and lies around in my apartement :/

styck, 2019-10-03:
I was able to use  "make menuconfig" and turn on some debugging then it got around this error.  Seems like a problem in the ESP32, I didn't see anything wrong with the heartypatch code, will investigate more this weekend.  Could be a hard problem if it works turning on debug and doesn't work when it is off.  I'd look for a timing issue then.

styck, 2019-10-04:
I got Bluetooth working, don't think it was code changes but more the changes in the sdkconfig file, I turned off the debugging.  Attached image shows the EliteHRV app and my calibrator showing 100bpm.

My fork has the updated code and configurations: https://github.com/styck/protocentral_heartypatch

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

chbardel, 2020-01-25:
Thanks for the code and your efforts I will try it out as soon as I have time!

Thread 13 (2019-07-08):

Infinite Loop (Reboot) Continuous ECG mode

Badr1600, 2019-07-08:
Error: 18:31:30.257 -> ESP_ERROR_CHECK failed: esp_err_t 0x110c at 0x400df5f5
18:31:30.257 -> file: "C:/msys32/home/100703599/esp/esp-idf/protocentral_heartypatch/firmware/heartypatch-stream-tcp/main/main.c" line 78
18:31:30.257 -> func: kalam_wifi_init
18:31:30.257 -> expression: esp_wifi_init(&cfg)

Complete Trace of Serial Monitor:

18:31:26.696 -> ⸮ets Jun  8 2016 00:22:57
18:31:28.562 ->
18:31:28.562 -> rst:0x1 (POWERON_RESET),boot:0x13 (SPI_FAST_FLASH_BOOT)
18:31:28.562 -> configsip: 0, SPIWP:0x00
18:31:28.562 -> clk_drv:0x00,q_drv:0x00,d_drv:0x00,cs0_drv:0x00,hd_drv:0x00,wp_drv:0x00
18:31:28.562 -> mode:DIO, clock div:3
18:31:28.562 -> load:0x3fff0008,len:8
18:31:28.562 -> load:0x3fff0010,len:4396
18:31:28.562 -> ho 0 tail 12 room 4
18:31:28.562 -> load:0x40078000,len:11080
18:31:28.562 -> ho 0 tail 12 room 4
18:31:28.562 -> load:0x40080000,len:252
18:31:28.562 -> entry 0x40080034
18:31:28.562 ->  [0;32mI (33) boot: ESP-IDF v2.1-dirty 2nd stage bootloader [0m
18:31:28.562 ->  [0;32mI (33) boot: compile time 18:24:24 [0m
18:31:28.562 ->  [0;32mI (60) boot: Enabling RNG early entropy source... [0m
18:31:28.562 ->  [0;32mI (60) boot: SPI Speed      : 26.7MHz [0m
18:31:28.562 ->  [0;32mI (61) boot: SPI Mode       : DIO [0m
18:31:28.562 ->  [0;32mI (73) boot: SPI Flash Size : 4MB [0m
18:31:28.562 ->  [0;32mI (85) boot: Partition Table: [0m
18:31:28.562 ->  [0;32mI (96) boot: ## Label            Usage          Type ST Offset   Length [0m
18:31:28.562 ->  [0;32mI (119) boot:  0 nvs              WiFi data        01 02 00009000 00006000 [0m
18:31:28.562 ->  [0;32mI (142) boot:  1 phy_init         RF data          01 01 0000f000 00001000 [0m
18:31:28.562 ->  [0;32mI (165) boot:  2 factory          factory app      00 00 00010000 00100000 [0m
18:31:28.562 ->  [0;32mI (189) boot: End of partition table [0m
18:31:28.562 ->  [0;32mI (202) boot: Disabling RNG early entropy source... [0m
18:31:28.562 ->  [0;32mI (219) boot: Loading app partition at offset 00010000 [0m
18:31:29.004 ->  [0;32mI (1142) boot: segment 0: paddr=0x00010018 vaddr=0x00000000 size=0x0ffe8 ( 65512)  [0m
18:31:29.004 ->  [0;32mI (1143) boot: segment 1: paddr=0x00020008 vaddr=0x3f400010 size=0x0dd20 ( 56608) map [0m
18:31:29.004 ->  [0;32mI (1159) boot: segment 2: paddr=0x0002dd30 vaddr=0x3ffb0000 size=0x02b1c ( 11036) load [0m
18:31:29.004 ->  [0;32mI (1192) boot: segment 3: paddr=0x00030854 vaddr=0x40080000 size=0x00400 (  1024) load [0m
18:31:29.004 ->  [0;32mI (1213) boot: segment 4: paddr=0x00030c5c vaddr=0x40080400 size=0x13a2c ( 80428) load [0m
18:31:29.004 ->  [0;32mI (1292) boot: segment 5: paddr=0x00044690 vaddr=0x400c0000 size=0x00000 (     0) load [0m
18:31:29.004 ->  [0;32mI (1293) boot: segment 6: paddr=0x00044698 vaddr=0x00000000 size=0x0b970 ( 47472)  [0m
18:31:29.004 ->  [0;32mI (1309) boot: segment 7: paddr=0x00050010 vaddr=0x400d0018 size=0x4bc9c (310428) map [0m
18:31:29.004 ->  [0;32mI (1335) cpu_start: Pro cpu up. [0m
18:31:29.004 ->  [0;32mI (1347) cpu_start: Starting app cpu, entry point is 0x40080ed4 [0m
18:31:29.004 ->  [0;32mI (0) cpu_start: App cpu up. [0m
18:31:29.004 ->  [0;32mI (1380) heap_alloc_caps: Initializing. RAM available for dynamic allocation: [0m
18:31:29.004 ->  [0;32mI (1402) heap_alloc_caps: At 3FFAE2A0 len 00001D60 (7 KiB): DRAM [0m
18:31:29.004 ->  [0;32mI (1423) heap_alloc_caps: At 3FFB8938 len 000276C8 (157 KiB): DRAM [0m
18:31:29.004 ->  [0;32mI (1444) heap_alloc_caps: At 3FFE0440 len 00003BC0 (14 KiB): D/IRAM [0m
18:31:29.004 ->  [0;32mI (1465) heap_alloc_caps: At 3FFE4350 len 0001BCB0 (111 KiB): D/IRAM [0m
18:31:29.004 ->  [0;32mI (1487) heap_alloc_caps: At 40093E2C len 0000C1D4 (48 KiB): IRAM [0m
18:31:29.004 ->  [0;32mI (1508) cpu_start: Pro cpu start user code [0m
18:31:29.004 ->  [0;32mI (1572) cpu_start: Starting scheduler on PRO CPU. [0m
18:31:29.004 ->  [0;32mI (212) cpu_start: Starting scheduler on APP CPU. [0m
18:31:29.614 ->  [0;32mI (837) heartypatch:: max30003_initchip setting SPS to 128 [0m
18:31:29.614 ->  [0;32mI (837) heartypatch:: max30003_initchip DHPF Disabled [0m
18:31:30.086 -> E (1341) wifi: misc_nvs_load 208 ret=4364
18:31:30.257 -> E (1341) wifi: wifi_init 1355 ret=4364
18:31:30.257 -> ESP_ERROR_CHECK failed: esp_err_t 0x110c at 0x400df5f5
18:31:30.257 -> file: "C:/msys32/home/100703599/esp/esp-idf/protocentral_heartypatch/firmware/heartypatch-stream-tcp/main/main.c" line 78
18:31:30.257 -> func: kalam_wifi_init
18:31:30.257 -> expression: esp_wifi_init(&cfg)
18:31:30.257 ->
18:31:30.257 -> Backtrace: 0x40087550:0x3ffb9790 0x400878cd:0x3ffb97b0 0x400df5f5:0x3ffb97d0 0x400df6fd:0x3ffb9890 0x400d0b42:0x3ffb98b0
18:31:30.257 ->
18:31:30.257 -> Rebooting...

Badr1600, 2019-07-08:
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

This message also is printed when using "make" to generate the .bin files for the Continuous ECG mode

styck, 2019-07-09:
I modified the code as shown below.  Keep in mind that I also used a newer tool chain than the one recommended.

//#ifdef CONFIG_MDNS_ENABLE
//      esp_err_t err = mdns_init(TCPIP_ADAPTER_IF_STA, &mdns);
//      ESP_ERROR_CHECK( mdns_set_hostname(mdns, KALAM32_MDNS_NAME) );
//      ESP_ERROR_CHECK( mdns_set_instance(mdns, KALAM32_MDNS_NAME) );
//#endif
#ifdef CONFIG_MDNS_ENABLE
      ESP_ERROR_CHECK( mdns_init() );
      ESP_ERROR_CHECK(mdns_hostname_set(KALAM32_MDNS_NAME));
      ESP_ERROR_CHECK(mdns_instance_name_set(KALAM32_MDNS_NAME));
#endif

Badr1600, 2019-07-10:
@styck still having the same issue. Can you share the .bin files that you built for the continuous ecg firmware to burn it directly to the module. just to verify the idea

styck, 2019-07-10:
This is a zip file with the bin and map file for my build.
[build.zip](https://github.com/Protocentral/protocentral_heartypatch/files/3379613/build.zip)

Badr1600, 2019-07-10:
I think there should be three .bin files heartypatch_tcp.bin, partitions_singleapp.bin and bootloader.bin right ??

styck, 2019-07-10:
Ok, added the bootloader.bin.

[HeartyPatchTCPBinary.zip](https://github.com/Protocentral/protocentral_heartypatch/files/3379706/HeartyPatchTCPBinary.zip)

Badr1600, 2019-07-11:
Great! the firmware is flashed successfully but what is the WiFi ssid and password that was used in the configuration file.

protocentralashwin, 2019-07-11:
Thanks @styck @Badr1600 for solving this issue.  We will upload a new release with the bin files for the continuous ECG mode.

Badr1600, 2019-07-11:
@protocentralashwin Thank you as I think there are some comparability issues with the current esp tool chain and esp-idf while building the firmware. Would be great if you update the instructions on the official website for setting up the firmware to the continuous ECG mode

Badr1600, 2019-07-13:
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

What is the version of tool chain have used ?

styck, 2019-07-13:
Today I just updated to the latest of everything following the instructions for Windows here: https://docs.espressif.com/projects/esp-idf/en/stable/get-started/index.html

There are only a few minor changes that had to be made to the heartypatch code, which I forked and will check in my changes, they just built but I have not tested on the device yet, will continue on this over the weekend.

I would like to add support for Wifi so I don't have to hard code the SSID and password, seems possible looking at: https://github.com/nkolban/esp32-snippets/tree/master/networking/bootwifi

Badr1600, 2019-07-14:
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

Working!!
Fix:
comment this line in file main.c since this attribute is never used and it always raises an error while building the firmware.
//mdns_server_t * mdns = NULL;

joicetm, 2019-07-16:
We are glad that you are able to fix it @Badr1600 @styck . We have updated the release with binaries with mdns and hard coded wifi ssid/password.

Closed 2019-07-15.

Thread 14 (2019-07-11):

Doco: Button and power state not explained

tbaumann, 2019-07-11:
The device has a button.

I believed it's the boot button for the ESP. Or is it power?
I can't actually tell.

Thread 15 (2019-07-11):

Hardware: Beware of original USB cable

tbaumann, 2019-07-11:
I had persistent issues flashing my new HeartyPatch.

Turns out, the USB cable delivered with the device is junk. It works fine with a good one.

To users: Toss it away.

To manufacturer: Leave it out. Everybody has a box full of USB cables. There is no need to bring more junk into the world.

protocentralashwin, 2019-07-11:
@tbaumann Thank you for the suggestion. We haven't seen this issue yet, but will watch out in our future batch of cables

Closed 2019-07-11.

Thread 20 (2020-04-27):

HeartyPatch doesn't show up w/ lsusb (on Linux)

etienneGrossmann, 2020-04-27:
I would like to flash my recently-received heartypatch, v2.3, as explained here https://heartypatch.protocentral.com/.

On my Linux desktop, lsusb does not see it.

How do I determine the port?

etienneGrossmann, 2020-04-29:
It now shows up. Was it because it was not charged?

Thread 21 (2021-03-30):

Basic diag for device

tralfamadude, 2021-03-30:
I want to use my v2.3 heartypatch again after a few years of sitting idle. Previously I got it to work with "Elite HRV" app on my iphone. Now the device is not detected by that app.

The charge LED goes on when it has usb power, but that red LED does not stay on for more than 30sec. Does that mean it is charged or something else?

I don't see it show up as a USB device on my macbook. Does that mean the device is broken?

The RGB LED never lights up.

dice2k, 2021-09-26:
Bottom line. Your electronics are probably still good... just a bad battery.

I just pulled my v2.3 out after a few years.

The Li-Po battery looked like a fat pillow. This means it has stopped working and will need a new battery. These batteries are easily replaceable but ideally will be removed and replaced using a soldering iron.

I am replacing mine with an 18650 LiFePo battery holder so I can simply replace the cells when needed.

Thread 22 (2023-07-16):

Migration to ESPhome?

SamSmith17, 2023-07-16:
Hi there, I have two heartypatches, and this repo seems defunct. That's just an observation, not a judgement, I know how it goes and appreciate all the work that went into this project.

I'm wondering if anyone knows how to port this project over to ESPhome for Home Assistant? It seems like this board is an ESP32 connected to a MAX30003 chip, basically like a stock ESP connected the to the Protocentral MAX30003 breakout board, just integrated into one board. ESPhome doesn't have a native component for the MAX30003 (yet) but I know that ESPhome configs can include C++ arduino code and libraries using the "Custom Component" template, and so I'm wondering if it might be possible to just use the ESP to push the R-R output values coming from the MAX30003 chip over wifi to HA so that they can be processed/filtered/interpreted elsewhere. In that case, I think the C++ code would only need to include the code and libraries for MAX chip and whatever signal processing may be necessary, and would not need to include the BLE or TCP functionality, which seems to be the majority of the code in this repo. I'm want to try it because these heartypatches I have aren't particularly useful to me running the stock firmware, but migrating to ESPhome is a bit above my paygrade, and so if anyone has input on how this might be done, or if there is a reason it absolutely cannot be done, I'd love to know. Is there a GPIO pin on the ESP I could set to just read the R-R output of the MAX30003?

Thanks for this project, these are neat little boards!

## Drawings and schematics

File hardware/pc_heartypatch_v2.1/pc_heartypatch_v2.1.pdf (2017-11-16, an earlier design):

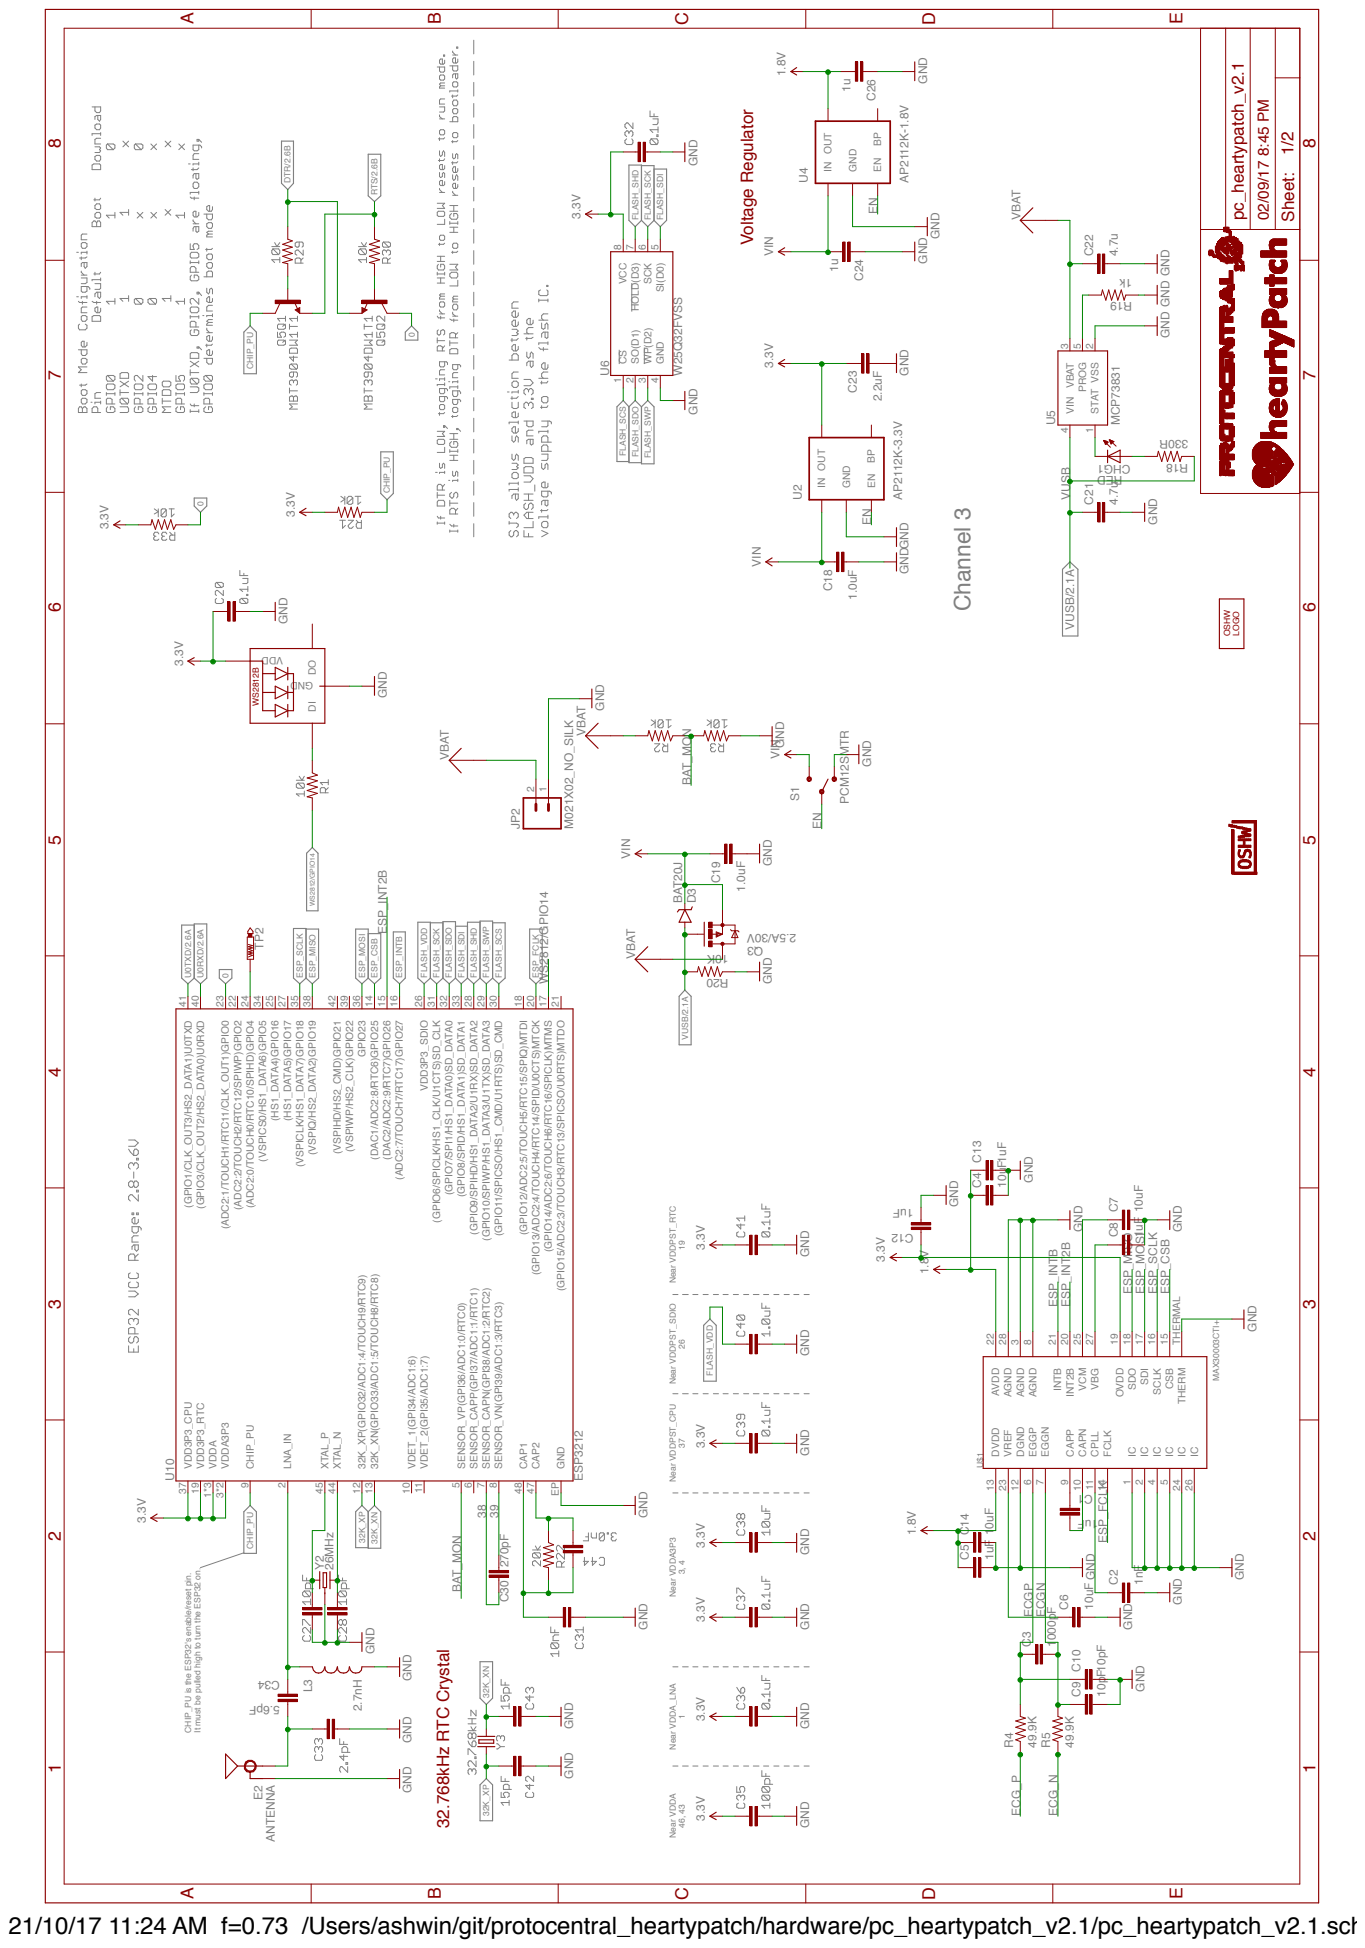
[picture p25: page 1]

GND 4 SCK 6 SI(D0) 5 SO(D1) 2 VCC 8

CSB 15 SCLK 16 SDI 17 SDO 18 OVDD 19

CHIP_PU is the ESP32's enable/reset pin.

It must be pulled high to turn the ESP32 on.

21/10/17 11:24 AM f=0.73 /Users/ashwin/git/protocentral_heartypatch/hardware/pc_heartypatch_v2.1/pc_heartypatch_v2.1.sch (Sheet: 1/2) Near VDDA 46, 43 Near VDDA_LNA

21/10/17 11:24 AM f=1.08 /Users/ashwin/git/protocentral_heartypatch/hardware/pc_heartypatch_v2.1/pc_heartypatch_v2.1.sch (Sheet: 2/2) GND MICRO⁻B | CP²¹⁰⁴ GND GND | GND

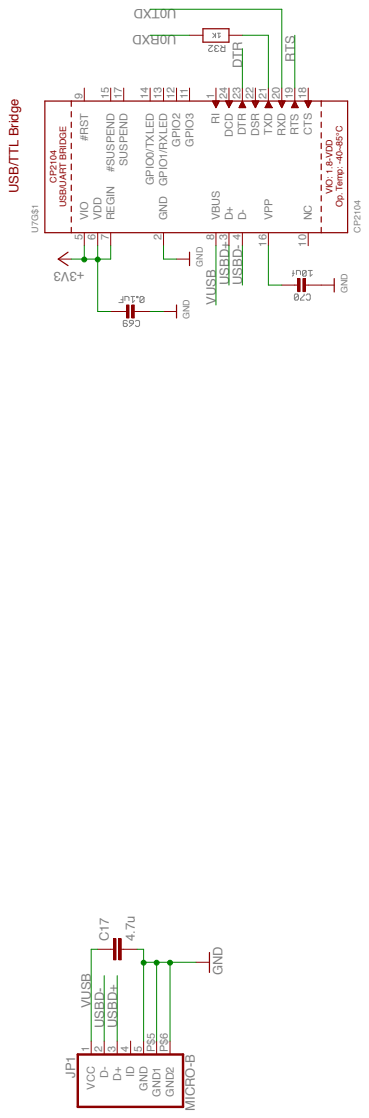
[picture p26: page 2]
VCC 1; GND 5; GND1 P$5; GND2 P$6; GND 2; VIO 5; VDD 6; REGIN 7; VBUS 8; #RST 9; GPIO3 11 GPIO2 12; DCD 24; DTR 23; DSR 22; TXD 21; RXD 20; RTS 19; CTS 18; SUSPEND 17; VPP 16; #SUSPEND 15; GPIO0/TXLED 14; GPIO1/RXLED 13; VUSB; USBD+; USBD-; RTS DTR; pc_heartypatch_v2.1; 2/2 Sheet:; VIO: 1.8-VDD; Op. Temp: -40~85°C

USB/TTL Bridge

USB/UART BRIDGE

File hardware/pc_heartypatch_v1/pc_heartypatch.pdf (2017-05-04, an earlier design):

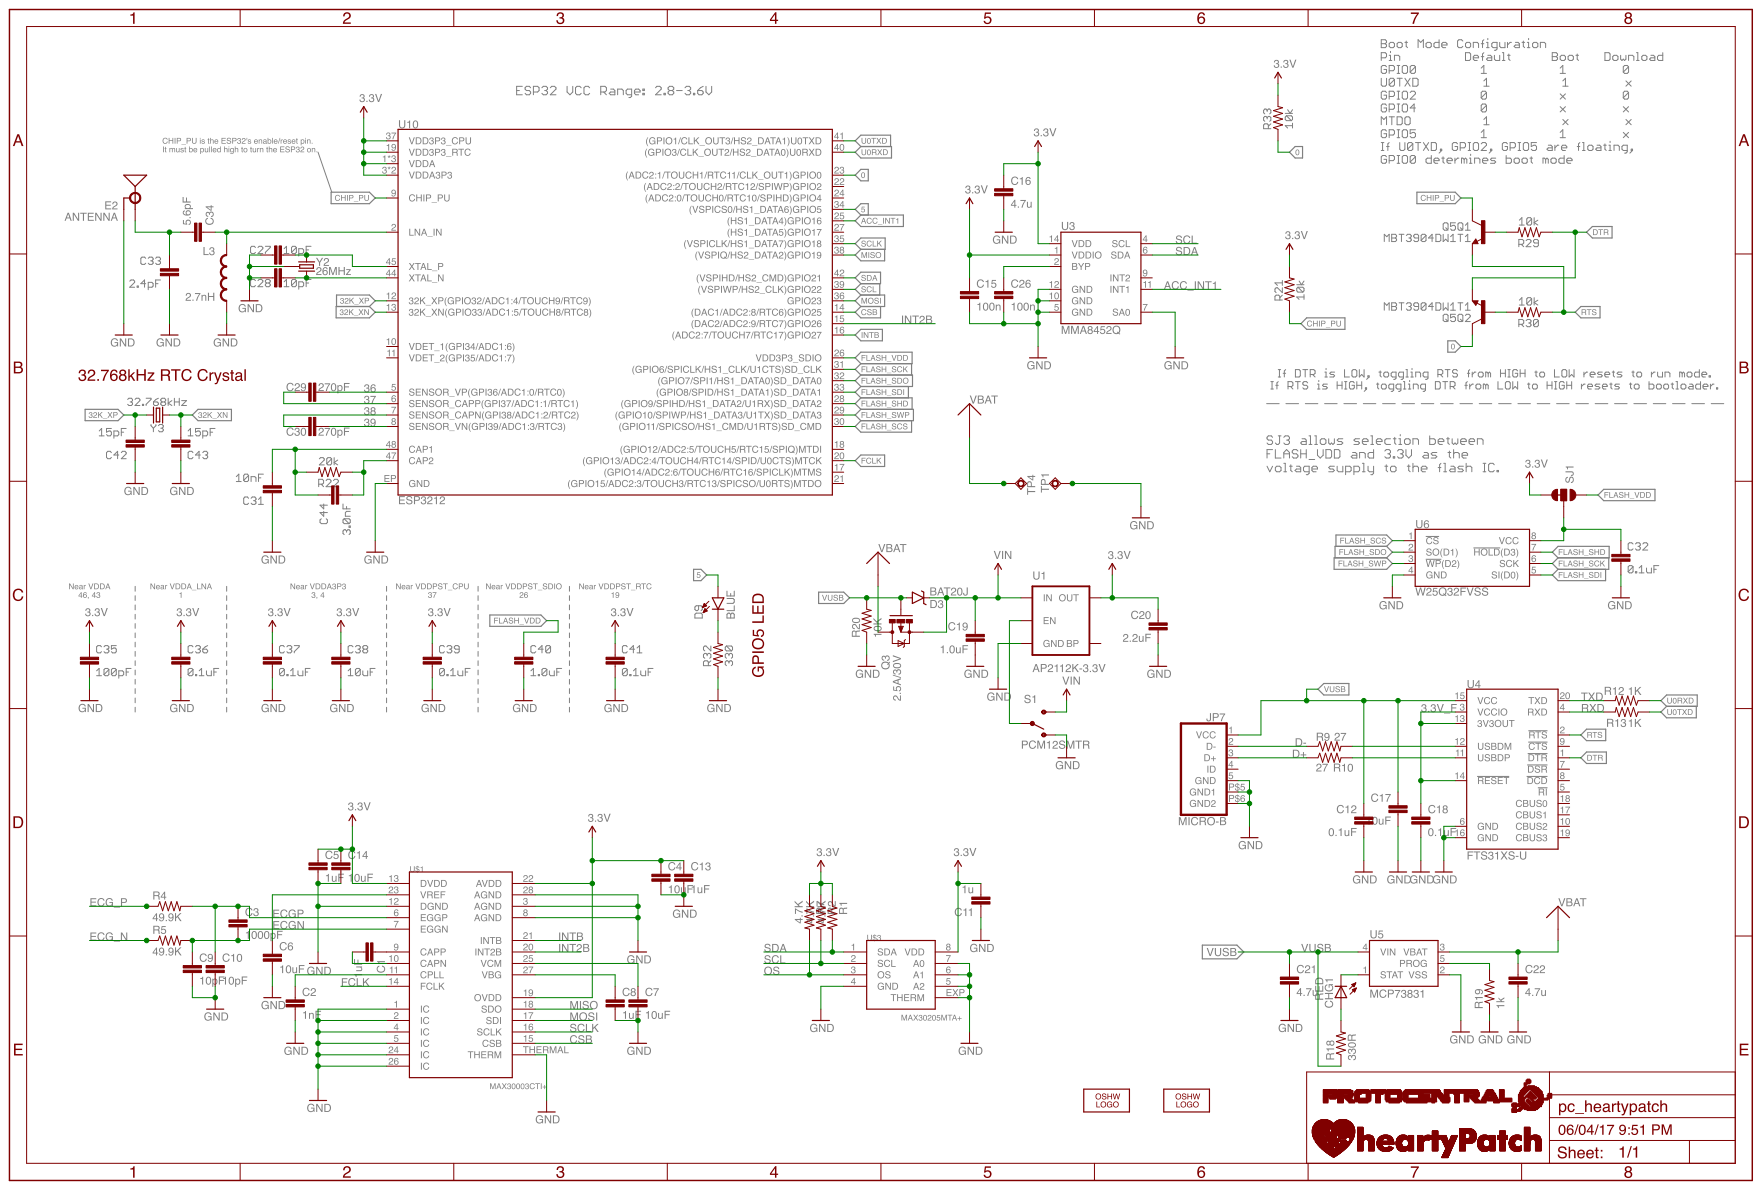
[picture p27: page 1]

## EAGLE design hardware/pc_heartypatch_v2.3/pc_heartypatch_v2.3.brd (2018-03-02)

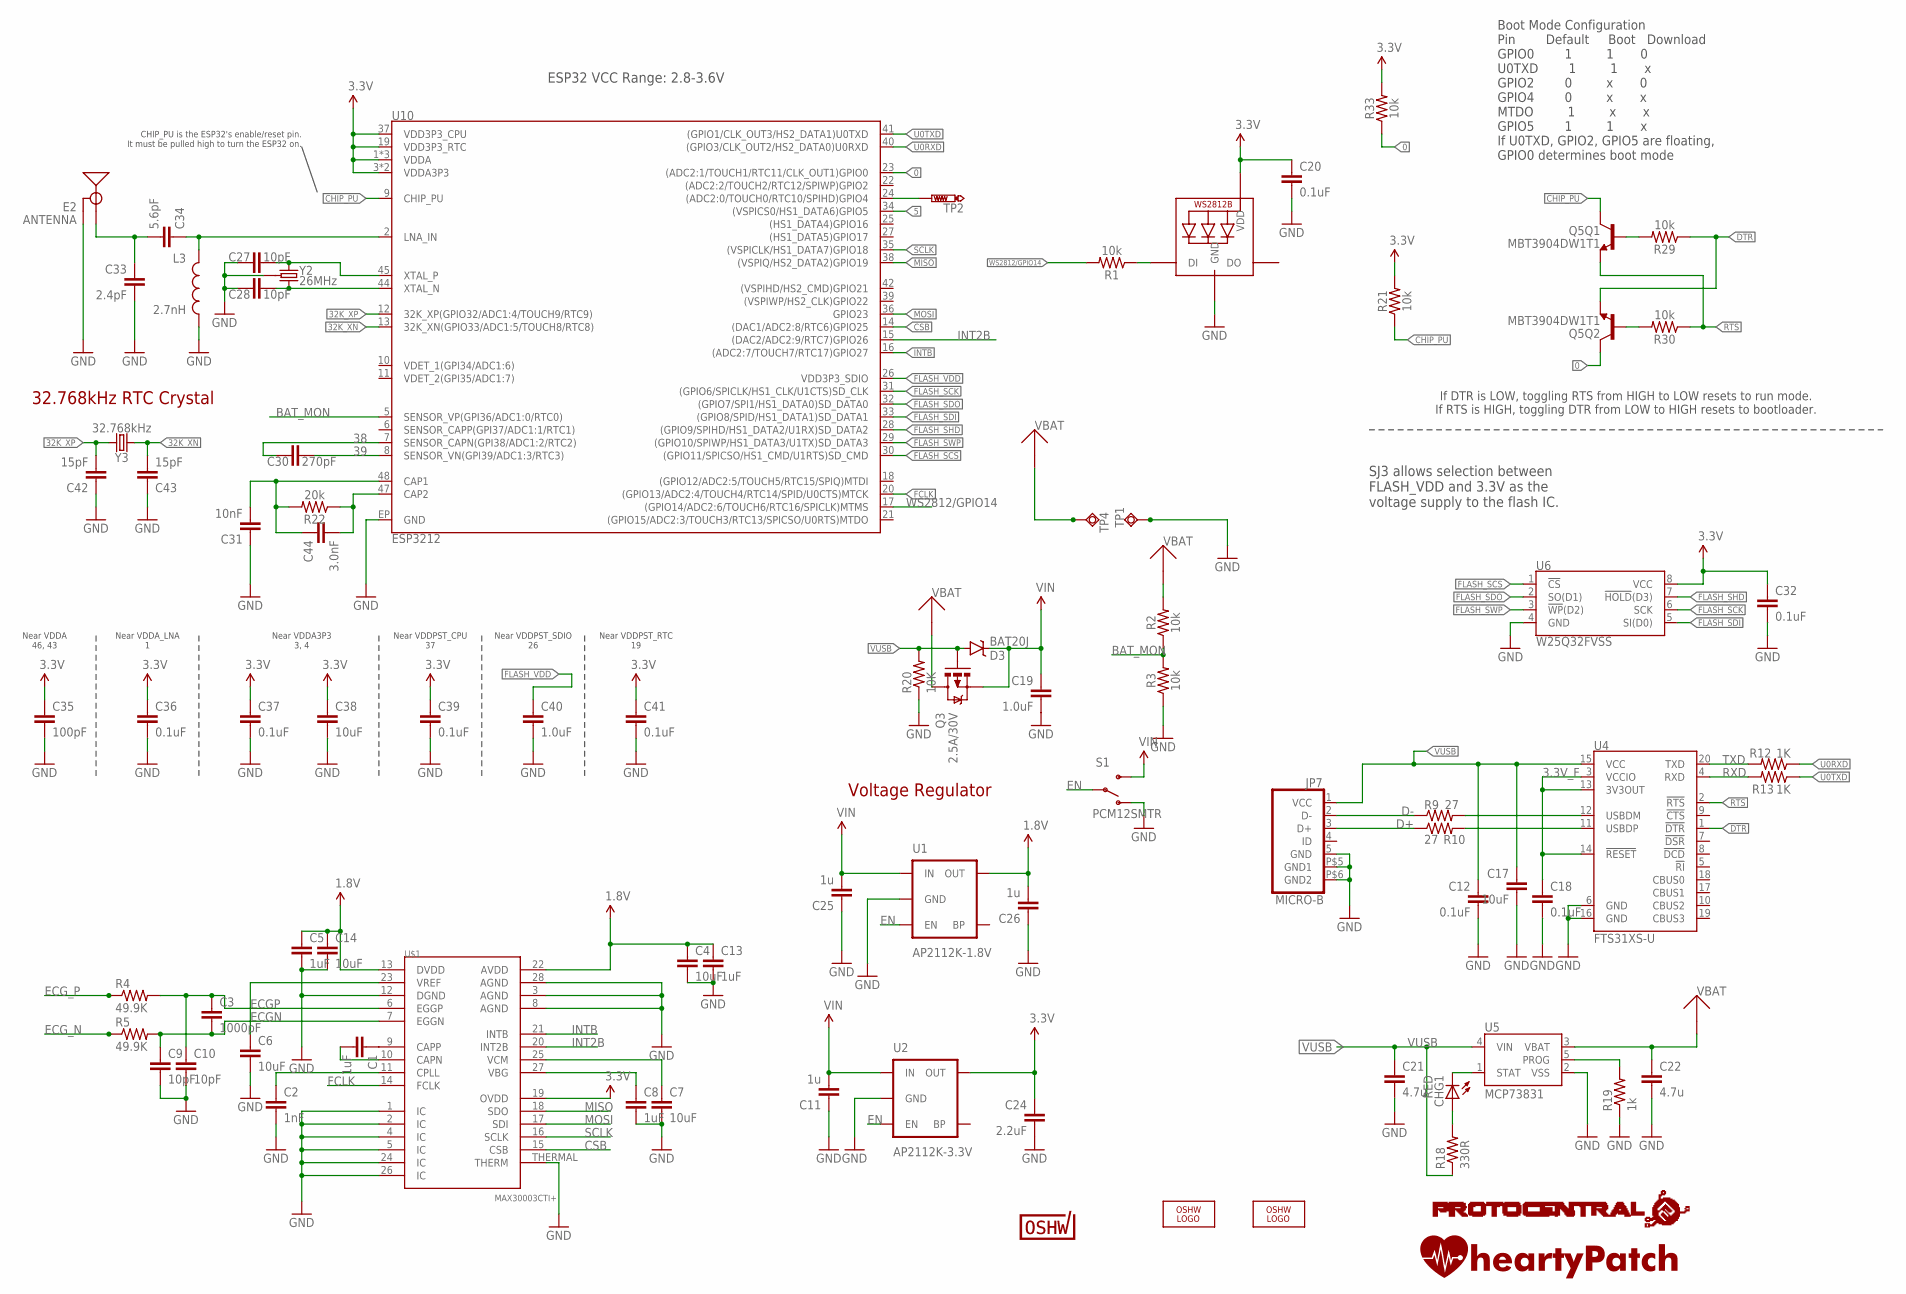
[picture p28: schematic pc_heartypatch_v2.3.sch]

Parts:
C1: 1uF; C0603
C2: 1nF; C0603
C3: 1000pF; C0402
C4, C6, C7, C17: 10uF; C0805
C5: 1uF; C0402
C8, C13: 1uF; C0805
C9, C10: 10pF; C0402
C11, C25, C26: 1u; C0402
C12, C18: 0.1uF; C0402
C14: 10uF; C0603
C19: 1.0uF; C0402
C20, C36, C37, C41: 0.1uF; 0603
C21, C22: 4.7u; C0805
C24: 2.2uF; C0402
C27, C28: 10pF; 0603
C30: 270pF; 0603
C31: 10nF; 0603
C32, C39: 0.1uF; 0402
C33: 2.4pF; 0603
C34: 5.6pF; 0603
C35: 100pF; 0603
C38: 10uF; 0603
C40: 1.0uF; 0603
C42, C43: 15pF; 0603
C44: 3.0nF; 0603
CHG1: RED; CHIPLED_0603
D3: BAT20J; SOD-323
E2: ANTENNA; TRACE_ANTENNA_2.4GHZ_25.7MM_TUNED
JP7: MICRO-B
L3: 2.7nH; 0603
LED1: WS2812B5050; WS2812B
LOGO1, LOGO2: OSHW_LOGO_FILLX0200-NT; OSHW_FILLX200_NOTEXT
Q3: 2.5A/30V; SOT23-3
Q5: MBT3904DW1T1; SC70-6
R1, R2, R3, R21, R29, R30, R33: 10k; 0603
R4, R5: 49.9K; 0805
R9, R10: 27; R0402
R12, R13: 1K; R0402
R18: 330R; R0402
R19: 1k; R0402
R20: 10K; R0402
R22: 20k; 0603
S1: PCM12SMTR; SWITCH-SPST-SMD-A
TP1, TP4: TPSQTP20SQ; TP20SQ
TP2: PTR1TP10SQ; TP10SQ
U1: AP2112K-1.8V; SOT23-5
U2: AP2112K-3.3V; SOT23-5
U4: FTS31XS-U; SSOP20_L
U5: MCP73831; SOT23-5
U6: W25Q32FVSS; SOIC-8
U10: ESP3212; QFN48-0.4MM
U$1: MAX30003CTI+; QFN-28
U$8: HEARTYPATCHHEART; HEARTYPATCH
U$9: PROTY_LOGO_WITH_TEXT; PROTY_WITH_TEXT
U$10: CERT-SMALL; CERT-SMALL-SILK
Y2: 26MHz; CRYSTAL-SMD-3.2X2.5
Y3: 32.768kHz; CRYSTAL-SMD-3.2X1.5MM

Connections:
0: Q5.6 (C), R33.1, U10.23 ((ADC2:1/TOUCH1/RTC11/CLK_OUT1)GPIO0)
1.8V: C4.1, C5.1, C13.1, C14.1, C26.2, U1.5 (OUT), U$1.13 (DVDD), U$1.22 (AVDD)
3.3V: C20.1, C24.1, C32.1, C35.1, C36.1, C37.1, C38.1, C39.1, C41.1, LED1.1-VDD (VDD), R21.2, R33.2, U2.5 (OUT), U6.8 (VCC), U10.1 (VDDA), U10.3 (VDDA3P3), U10.4 (VDDA3P3), U10.19 (VDD3P3_RTC), U10.37 (VDD3P3_CPU), U10.43 (VDDA), U10.46 (VDDA), U$1.19 (OVDD)
3.3V_F: C18.1, U4.3 (VCCIO), U4.13 (3V3OUT), U4.14 (!RESET)
5: U10.34 ((VSPICS0/HS1_DATA6)GPIO5)
32K_XN: C43.2, U10.13 (32K_XN(GPIO33/ADC1:5/TOUCH8/RTC8)), Y3.P$2 (2)
32K_XP: C42.2, U10.12 (32K_XP(GPIO32/ADC1:4/TOUCH9/RTC9)), Y3.P$1 (1)
38: C30.1, U10.7 (SENSOR_CAPN(GPI38/ADC1:2/RTC2))
39: C30.2, U10.8 (SENSOR_VN(GPI39/ADC1:3/RTC3))
BAT_MON: R2.1, R3.2, U10.5 (SENSOR_VP(GPI36/ADC1:0/RTC0))
CAP_10N: C31.2, C44.1, R22.2, U10.48 (CAP1)
CHIP_PU: Q5.3 (C), R21.1, U10.9 (CHIP_PU)
CSB: U10.14 ((DAC1/ADC2:8/RTC6)GPIO25), U$1.15 (CSB)
D+: JP7.3 (D+), R10.1
D-: JP7.2 (D-), R9.1
DTR: Q5.1 (E), R29.1, U4.1 (!DTR)
ECGN: C3.2, C9.1, R5.2, U$1.7 (EGGN)
ECGP: C3.1, C10.1, R4.2, U$1.6 (EGGP)
ECG_N: R5.1
ECG_P: R4.1
EN: S1.2, U1.3 (EN), U2.3 (EN)
FCLK: U10.20 ((GPIO13/ADC2:4/TOUCH4/RTC14/SPID/U0CTS)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), U$1.14 (FCLK)
FLASH_SCK: U6.6 (SCK), U10.31 ((GPIO6/SPICLK/HS1_CLK/U1CTS)SD_CLK)
FLASH_SCS: U6.1 (!CS!), U10.30 ((GPIO11/SPICSO/HS1_CMD/U1RTS)SD_CMD)
FLASH_SDI: U6.5 (SI(D0)), U10.33 ((GPIO8/SPID/HS1_DATA1)SD_DATA1)
FLASH_SDO: U6.2 (SO(D1)), U10.32 ((GPIO7/SPI1/HS1_DATA0)SD_DATA0)
FLASH_SHD: U6.7 (!HOLD!(D3)), U10.28 ((GPIO9/SPIHD/HS1_DATA2/U1RX)SD_DATA2)
FLASH_SWP: U6.3 (!WP!(D2)), U10.29 ((GPIO10/SPIWP/HS1_DATA3/U1TX)SD_DATA3)
FLASH_VDD: C40.1, U10.26 (VDD3P3_SDIO)
GND: C2.2, C4.2, C5.2, C6.2, C7.2, C8.2, C9.2, C10.2, C11.1, C12.2, C13.2, C14.2, C17.2, C18.2, C19.2, C20.2, C21.2, C22.2, C24.2, C25.1, C26.1, C27.1, C28.1, C31.1, C32.2, C33.2, C35.2, C36.2, C37.2, C38.2, C39.2, C40.2, C41.2, C42.1, C43.1, E2.GND, E2.GND2 (GND), JP7.5 (GND), JP7.P$5 (GND1), JP7.P$6 (GND2), L3.2, LED1.3-GND (GND), R3.1, R19.1, R20.1, S1.1 (O), TP1.TP, U1.2 (GND), U2.2 (GND), U4.6 (GND), U4.16 (GND), U5.2 (VSS), U6.4 (GND), U10.EP (GND), U$1.1 (IC), U$1.2 (IC), U$1.3 (AGND), U$1.4 (IC), U$1.5 (IC), U$1.8 (AGND), U$1.12 (DGND), U$1.24 (IC), U$1.26 (IC), U$1.28 (AGND), U$1.THERMAL (THERM), Y2.2 (GND), Y2.4 (GND)
INT2B: U10.15 ((DAC2/ADC2:9/RTC7)GPIO26), U$1.20 (INT2B)
INTB: U10.16 ((ADC2:7/TOUCH7/RTC17)GPIO27), U$1.21 (INTB)
LNA_IN: C34.1, L3.1, U10.2 (LNA_IN)
MISO: U10.38 ((VSPIQ/HS2_DATA2)GPIO19), U$1.18 (SDO)
MOSI: U10.36 (GPIO23), U$1.17 (SDI)
unnamed: LED1.4-DIN (DI), R1.1
unnamed: C6.1, U$1.23 (VREF)
unnamed: C1.1, U$1.9 (CAPP)
unnamed: TP2.TP, U10.24 ((ADC2:0/TOUCH0/RTC10/SPIHD)GPIO4)
unnamed: CHG1.C, U5.1 (STAT)
unnamed: C1.2, U$1.10 (CAPN)
unnamed: C2.1, U$1.11 (CPLL)
unnamed: R9.2, U4.12 (USBDM)
unnamed: R10.2, U4.11 (USBDP)
unnamed: C7.1, U$1.25 (VCM)
unnamed: C8.1, U$1.27 (VBG)
unnamed: CHG1.A, R18.2
unnamed: R19.2, U5.5 (PROG)
unnamed: Q5.5 (B), R29.2
unnamed: Q5.2 (B), R30.2
unnamed: C27.2, U10.45 (XTAL_P), Y2.1
unnamed: C28.2, U10.44 (XTAL_N), Y2.3 (2)
unnamed: C44.2, R22.1, U10.47 (CAP2)
RTS: Q5.4 (E), R30.1, U4.2 (!RTS)
RXD: R13.2, U4.4 (RXD)
SCLK: U10.35 ((VSPICLK/HS1_DATA7)GPIO18), U$1.16 (SCLK)
TRACE_ANT1: C33.1, C34.2, E2.ANT (SIGNAL)
TXD: R12.2, U4.20 (TXD)
U0RXD: R12.1, U10.40 ((GPIO3/CLK_OUT2/HS2_DATA0)U0RXD)
U0TXD: R13.1, U10.41 ((GPIO1/CLK_OUT3/HS2_DATA1)U0TXD)
VBAT: C22.1, Q3.3 (D), R2.2, TP4.TP, U5.3 (VBAT)
VIN: C11.2, C19.1, C25.2, D3.C, Q3.2 (S), S1.3 (S), U1.1 (IN), U2.1 (IN)
VUSB: C12.1, C17.1, C21.1, D3.A, JP7.1 (VCC), Q3.1 (G), R18.1, R20.2, U4.15 (VCC), U5.4 (VIN)
WS2812/GPIO14: R1.2, U10.17 ((GPIO14/ADC2:6/TOUCH6/RTC16/SPICLK)MTMS)

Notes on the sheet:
Boot Mode Configuration Pin Default Boot Download GPIO0 1 1 0 U0TXD 1 1 x GPIO2 0 x 0 GPIO4 0 x x MTDO 1 x x GPIO5 1 1 x If U0TXD, GPIO2, GPIO5 are floating, GPIO0 determines boot mode
Near VDDA 46, 43
Near VDDA_LNA 1
Near VDDA3P3 3, 4
Near VDDPST_CPU 37
Near VDDPST_SDIO 26
Near VDDPST_RTC 19
32.768kHz RTC Crystal
ESP32 VCC Range: 2.8-3.6V
SJ3 allows selection between FLASH_VDD and 3.3V as the voltage supply to the flash IC.
If DTR is LOW, toggling RTS from HIGH to LOW resets to run mode. If RTS is HIGH, toggling DTR from LOW to HIGH resets to bootloader.
CHIP_PU is the ESP32's enable/reset pin. It must be pulled high to turn the ESP32 on.
Voltage Regulator

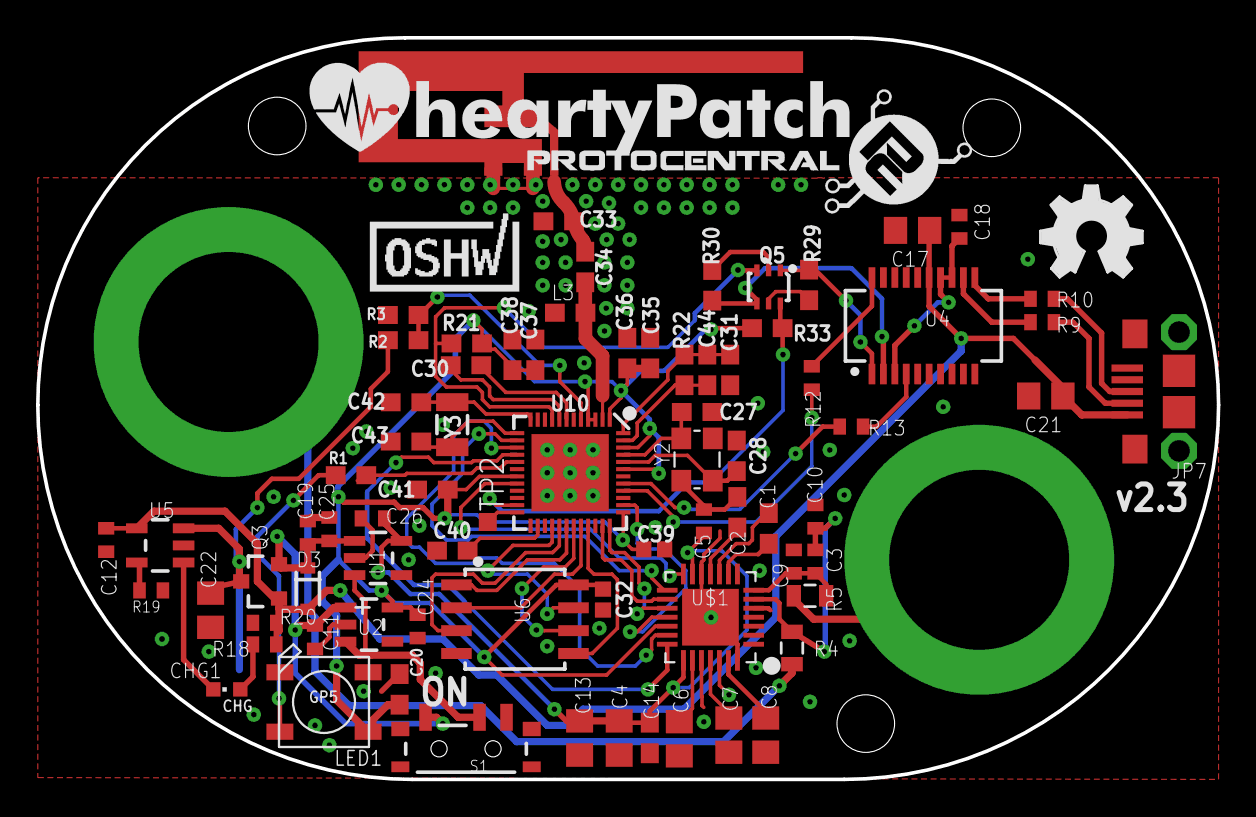
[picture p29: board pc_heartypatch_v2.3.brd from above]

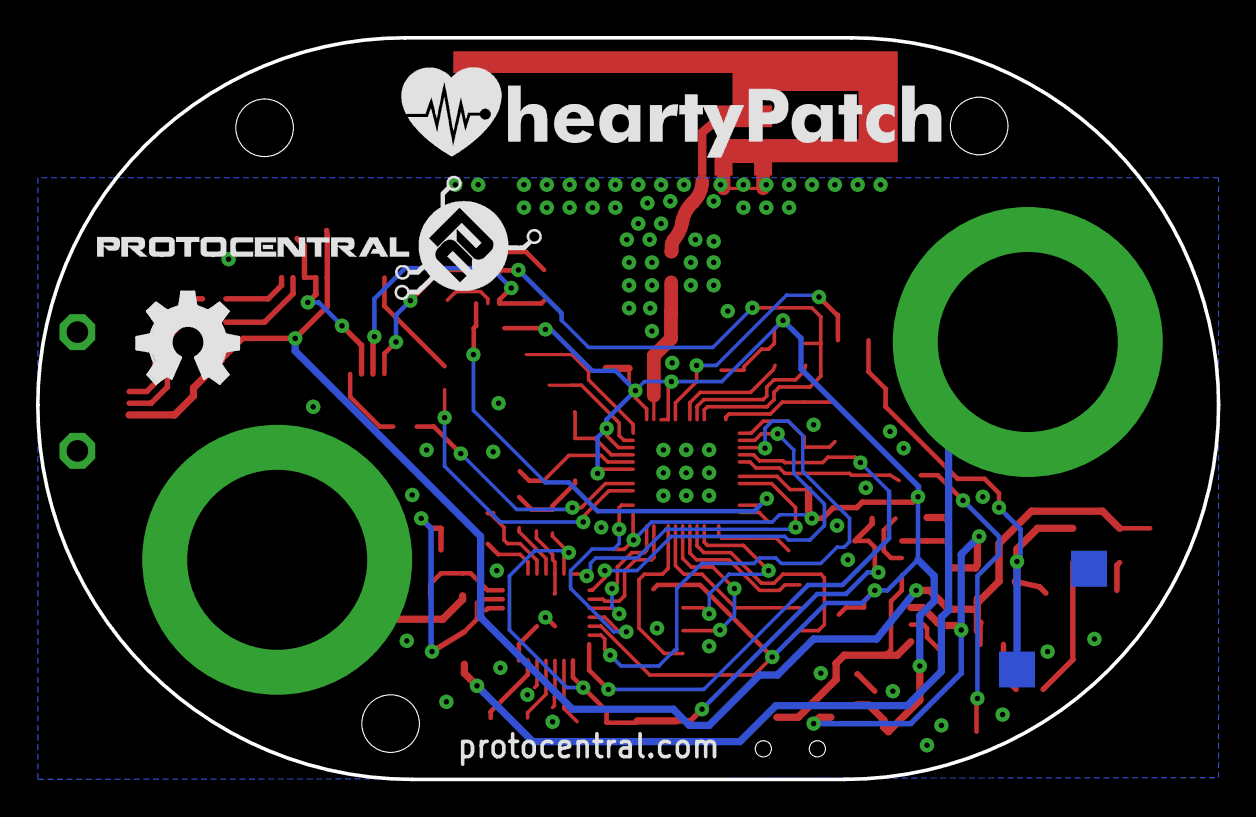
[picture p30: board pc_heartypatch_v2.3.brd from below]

Board: 4 copper layers, 65.6 x 41.2 mm, 85 parts (5 on the bottom side), 61 nets.

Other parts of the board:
U$4: HEARTYPATCHHEART; HEARTYPATCH
U$7: PROTY_LOGO_WITH_TEXT; PROTY_WITH_TEXT

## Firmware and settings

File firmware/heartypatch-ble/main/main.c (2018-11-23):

#include <stdio.h>
#include <stdlib.h>
#include <string.h>
#include <sys/socket.h>

#include "freertos/FreeRTOS.h"
#include "freertos/task.h"
#include "freertos/event_groups.h"
#include "esp_wifi.h"
#include "esp_system.h"
#include "esp_event.h"
#include "esp_event_loop.h"
#include "nvs_flash.h"
#include "driver/gpio.h"
#include "driver/spi_master.h"
#include "driver/ledc.h"
#include "bt.h"				//use this for esp-idf versions below 3.0 
#include "driver/i2c.h"
#include "driver/uart.h"
#include "driver/sdmmc_host.h"

#include "esp_log.h"
#include "heartypatch_main.h"
#include "heartypatch_max30003.h"
#include "heartypatch_tcp_server.h"
#include "heartypatch_ble.h"
#include "heartypatch_adc.h"

#define TAG "heartypatch:"
#define delay_ms(ms) vTaskDelay((ms) / portTICK_RATE_MS)

#define BUF_SIZE  1000

extern xSemaphoreHandle print_mux;
char uart_data[50];
const int uart_num = UART_NUM_1;
uint8_t* db;

static EventGroupHandle_t wifi_event_group;
const int CONNECTED_BIT_kalam = BIT0;

uint8_t* db;
unsigned int global_heartRate ; 

extern QueueHandle_t xQueue_tcp;

static esp_err_t event_handler(void *ctx, system_event_t *event)
{
    switch(event->event_id) {
    case SYSTEM_EVENT_STA_START:
        esp_wifi_connect();
        break;
    case SYSTEM_EVENT_STA_GOT_IP:
        xEventGroupSetBits(wifi_event_group, CONNECTED_BIT_kalam);
        break;
    case SYSTEM_EVENT_STA_DISCONNECTED:
        esp_wifi_connect();
        xEventGroupClearBits(wifi_event_group, CONNECTED_BIT_kalam);
        break;
    default:
        break;
    }
    return ESP_OK;
}

void heartypatch_wifi_init(void)
{
    tcpip_adapter_init();
    wifi_event_group = xEventGroupCreate();
    ESP_ERROR_CHECK( esp_event_loop_init(event_handler, NULL) );
    wifi_init_config_t cfg = WIFI_INIT_CONFIG_DEFAULT();
    ESP_ERROR_CHECK( esp_wifi_init(&cfg) );
    ESP_ERROR_CHECK( esp_wifi_set_storage(WIFI_STORAGE_RAM) );
    wifi_config_t wifi_config = {
          .sta = {
              .ssid = CONFIG_WIFI_SSID,
              .password = CONFIG_WIFI_PASSWORD,
          },
    };
    ESP_LOGI(TAG, "Setting WiFi configuration SSID %s...", wifi_config.sta.ssid);
    ESP_ERROR_CHECK( esp_wifi_set_mode(WIFI_MODE_STA) );
    ESP_ERROR_CHECK( esp_wifi_set_config(WIFI_IF_STA, &wifi_config) );
    ESP_ERROR_CHECK( esp_wifi_start() );

}


void app_main(void)
{

    // Initialize NVS.
	esp_err_t ret;
    ret = nvs_flash_init();
    if (ret == ESP_ERR_NVS_NO_FREE_PAGES) {
        ESP_ERROR_CHECK(nvs_flash_erase());
        ret = nvs_flash_init();
    }
    ESP_ERROR_CHECK( ret );
	
	xQueue_tcp = xQueueCreate(20, sizeof( struct Tcp_Message *));
	if( xQueue_tcp==NULL )
	{
		ESP_LOGI(TAG, "Failed to create Queue..!");
	}
	
    max30003_initchip(PIN_SPI_MISO,PIN_SPI_MOSI,PIN_SPI_SCK,PIN_SPI_CS);

    heartypatch_start_max30003();
    heartypatch_adc_start();

	vTaskDelay(2000/ portTICK_PERIOD_MS);		//give sometime for max to settle

#ifdef CONFIG_BLE_MODE_ENABLE
	heartypatch_ble_Init();		
#endif
	
#ifdef CONFIG_WIFIMODE_ENABLE					//configure the ssid/password under makemenuconfig/heartypatch configuration.
	heartypatch_wifi_init();
    /* Wait for WiFI to show as connected */
    xEventGroupWaitBits(wifi_event_group, CONNECTED_BIT_kalam,false, true, portMAX_DELAY);
    
	/*only hr and rr is sending through tcp, to plot ECG, you need to configure the max30003 to read ecg data */
	vTaskDelay(500/ portTICK_PERIOD_MS);
    heartypatch_tcp_start();
#endif
     
	
}

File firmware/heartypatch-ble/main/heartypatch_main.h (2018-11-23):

#ifndef heartypatch_main_h
#define heartypatch_main_h

#define PIN_NUM_0   17
#define PIN_NUM_1   14
#define PIN_NUM_2   13
#define PIN_NUM_4   2
#define PIN_NUM_5   16
#define PIN_NUM_6   26
#define PIN_NUM_7   17
#define PIN_NUM_8   25
#define PIN_NUM_10  12
#define PIN_NUM_11  23
#define PIN_NUM_12  19
#define PIN_NUM_13  18

#define PIN_NUM_A0  35
#define PIN_NUM_A1  34
#define PIN_NUM_A2  36
#define PIN_NUM_A3  39

#define PIN_I2C_SDA  21
#define PIN_I2C_SCL  22

#define PIN_SPI_CS   25
#define PIN_SPI_MOSI 23
#define PIN_SPI_MISO 19
#define PIN_SPI_SCK  18

#endif

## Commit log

2017-05-04 Init new repository
    [pc_heartypatch.brd, pc_heartypatch.sch]
2017-07-22 Added new firmware for Hearty
    1. Interrupt Driven Code
    2. Support for BLE
2017-07-22 Added HeartyPatch enclosure files
    [PCB Bottom Cover with hooks - ShWallHt (1).stl, PCB Bottom Cover with hooks - ShWallHt.stl, PCB Bottom Cover with hooks.stl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]
2017-08-20 Added new v3 board and schematic
    [pc_heartypatch_v2.brd, pc_heartypatch_v2.sch, pc_heartypatch_v2.xls]
2017-09-30 Updated and organised all Firmware/GUI
    [HeartyPatch_ case_v2.1_bottom.stl, HeartyPatch_ case_v2.1_top.stl, PCB Bottom Cover with hooks - ShWallHt (1).stl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]
2018-02-26 Bugfix update for TCP server firmware and GUI software
    [kalam32_tcp_server.c, max30003.c, protocentral_heartypatch_gui_tcp.pde]
2018-03-02 Added HeartyPatch v2.3 schematics
    [pc_heartypatch_v2.3.brd, pc_heartypatch_v2.3.sch]
2018-03-09 Fix sample rate consistency issue
    ALso make sample rate of DHPF configurable at from menuconfig
    [kalam32_tcp_server.c, max30003.c]
2018-03-11 Configurable samples per packet
    Still limitted to legacy packet size
2018-03-14 Quiesce send_data between connections
    Optimize power by putting Max30003 in default state between connections

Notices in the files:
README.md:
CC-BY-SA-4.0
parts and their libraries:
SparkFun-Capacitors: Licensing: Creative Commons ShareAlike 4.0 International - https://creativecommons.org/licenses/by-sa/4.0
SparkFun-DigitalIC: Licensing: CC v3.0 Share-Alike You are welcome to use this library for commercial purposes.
